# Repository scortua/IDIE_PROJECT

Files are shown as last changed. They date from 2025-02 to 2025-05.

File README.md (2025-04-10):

#### Diseño de un Sistema de Monitoreo de Vibraciones IoT con Conectividad LoRaWAN
# ECI (https://www.escuelaing.edu.co/)PROYECTO INTEGRACIÓN DISPOSITIVOS ELECTRÓNICOS

<p align="center">
  
  
  
  
  
</p>

## Índice
* [PCB](#diseño-pcb)
* [3D](#diseño-3d)

## Entregables del Proyecto

### Entregable 1: Documentación Técnica y Conceptual
La guía se encuentra en el archivo _Markdown_ [Base entregable 1](./ent1.md) y abarca:
- **Introducción:** Presentación del proyecto, la motivación y los objetivos.
- **Detalle del Producto:** Especificaciones técnicas, características físicas y funcionales del dispositivo IoT.
- **Alcance de los Servicios Ofertados:** Descripción de los servicios incluidos, como el diseño de hardware, firmware, pruebas y documentación completa.
- **Exclusiones del Alcance:** Elementos y servicios que no se consideran en el proyecto (producción en masa, logística, etc.).
- **Valor:** Análisis de costos, desglose de inversión y metodologías de cálculo.
- **Cronograma de Trabajo:** Fases del proyecto y tiempo estimado para cada etapa.
- **Tiempo de Entrega:** Fechas clave y plazos para los entregables parciales y finales.

---

### Entregable 2: Diseño y Sustentación Técnica
Disponible en el archivo _Markdown_ [Base entregable 2](./ent2.md), este entregable se compone de:
- **Sustentación del Diseño:** Presentación y defensa del diseño, representando un 30% de la evaluación.
- **Informe Digital Detallado (35%):**
  - Descripción general de la solución y su justificación.
  - Diagramas de bloques que ilustren el flujo y la estructura de la solución.
  - Descripción detallada de cada bloque (funciones y relaciones).
  - Relación entre la solución y los requerimientos solicitados.
  - Especificaciones técnicas de los componentes electrónicos clave (MCU, memorias, fuentes, interfaces, etc.).
  - Diseño esquemático del sistema.
  - Diseño de PCB, presentando cada capa (máscara de componentes, anti-soldadura, crema, cobre y perforaciones).
  - Lista de materiales (BOM List).
  - Modelo 3D del producto final.
  - Cuadro de costos de producción para diferentes volúmenes (1, 10, 100, 500, 1000 y 5000 unidades).
- **Paquete Digital Adicional (35%):**
  - Informe en PDF con toda la documentación.
  - Archivo PDF del esquemático.
  - Archivos GERBER del diseño de la PCB.
  - Archivo BOM en Excel.
  - Archivo STEP o STL del modelo 3D.
  - Hoja de cálculo para el cuadro de costos, con fórmula automática según la cantidad a producir.
  - Hojas de datos (datasheets) de los componentes principales.

---

### Entregable 3: Manuales, Brochure y Prototipo Final
La guía se encuentra en [Base entregable 3](./ent3.md) y comprende:
- **Manual de Usuario:** Documento PDF que explica el funcionamiento y manejo del dispositivo (10%).
- **Brochure del Producto:** Ficha comercial en PDF que resalta las ventajas competitivas y características principales (10%).
- **Informe Digital Actualizado (20%):**
  - Descripción del firmware desarrollado y su funcionamiento.
  - Diagrama de flujo de la aplicación.
  - Detalle de los drivers implementados.
  - Retos y dificultades enfrentadas junto con las soluciones aplicadas.
  - Conclusiones finales y lecciones aprendidas.
  - Inclusión y actualización del paquete digital definido en el Entregable 2.
- **Prototipo Final Funcional:** Durante la presentación, se evaluarán todas las características y funcionalidades estipuladas en el proyecto (60%).

Cada uno de estos entregables está diseñado para garantizar una documentación integral y una validación exhaustiva del proyecto, cubriendo desde la concepción de la idea hasta la demostración práctica del sistema IoT.

# DISEÑO GENERAL
Antes de comenzar es necesario buscar sobre dispositivos similares y si existen, toda la idea de los componentes principales que tienen sus características principales en el diseño y después los requeridos para el funcionamiento de lo necesario.

## Diseño PCB
<p align="center">
  
</p>
<details>
<summary> Dimensiones </summary>
Primer paso fue construir la PCB que entrara a la perfección dentro de la caja seleccionada que se ve a continuación.

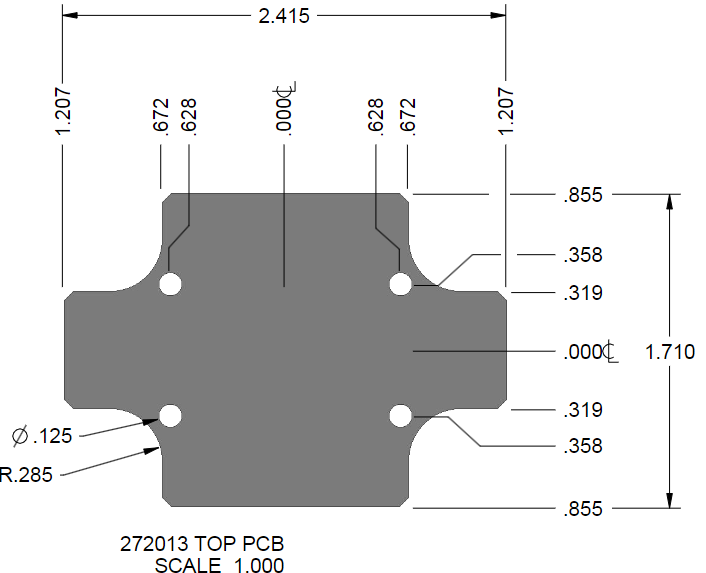
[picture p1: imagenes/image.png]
Caja


Estas medidas se siguieron al pie de la letra para poder diseñar a la perfección la PCB y el circuito que se desea.
</details>

## Componentes
#### Componentes Usados

A continuación se describen los dispositivos fundamentales utilizados en el proyecto, documentados en los archivos PDF disponibles:

- **Socket Batería:** ([1015-socketbattery.pdf](./Documentos/1015-socketbattery.pdf))  
  Se especifica el diseño del conector para integración segura y confiable del paquete de alimentación.

- **Cristal Oscilador:** ([ABS06-cristal.pdf](./Documentos/ABS06-cristal.pdf))  
  Fundamental para la sincronización de circuitos, garantizando estabilidad y precisión en el reloj del sistema.

- **Bobina y Núcleo de Ferrita:** ([core_ferrita-coil.pdf](./Documentos/core_ferrita-coil.pdf))  
  Componentes críticos en la filtración y manejo de interferencias electromagnéticas en el circuito.

- **Convertidor Serial:** ([DS_FT234XD-serialconverter.pdf](./Documentos/DS_FT234XD-serialconverter.pdf))  
  Facilita la comunicación entre el microcontrolador y dispositivos externos mediante interfaces USB y serie.

- **Unidad de Medición Inercial (IMU):** ([FXLS8974CFR3-imu.pdf](./Documentos/FXLS8974CFR3-imu.pdf))  
  Incorpora sensores que permiten la detección y el análisis de movimientos y vibraciones, contribuyendo a la monitorización del estado del dispositivo.

- **Sensor de Efecto Hall:** ([hall_efect-sensor.pdf](./Documentos/hall_efect-sensor.pdf))  
  Utilizado para detectar cambios en campos magnéticos, lo que aporta datos relevantes en aplicaciones de control de propiedad magnética.

- **LED RGB:** ([HB_CLY6D-rgb_led.pdf](./Documentos/HB_CLY6D-rgb_led.pdf))  
  Proporciona indicadores visuales para el estado del sistema, útil para diagnósticos o notificaciones.

- **Módulo LoRa:** ([LoRa_E5_module.pdf](./Documentos/LoRa_E5_module.pdf))  
  Es el componente clave para la conexión IoT a través de la red LoRaWAN, permitiendo la transmisión de datos a larga distancia.

- **Transistor y MOSFET:** ([transistor.pdf](./Documentos/transistor.pdf), [SI2305B_SOT_23-mosfet.pdf](./Documentos/SI2305B_SOT_23-mosfet.pdf))  
  Empleados para la gestión de señales y el control de potencia dentro del circuito integrado.

- **Microcontrolador:** ([stm32l071v8-micro.pdf](./Documentos/stm32l071v8-micro.pdf))  
  El cerebro del sistema, encargado de coordinar las comunicaciones, procesar las señales de los sensores y gestionar las acciones del dispositivo.

- **Protección de Diodos:** ([usblc6_2SY6-diode-protection.pdf](./Documentos/usblc6_2SY6-diode-protection.pdf))  
  Asegura la integridad del circuito frente a sobretensiones y otros picos de corriente, protegiendo los componentes sensibles.

- **Antena:** ([W2311-antenna.pdf](./Documentos/W2311-antenna.pdf))
  La antena es un componente crítico en la conexión IoT a través de LoRaWAN. Su función es asegurar una comunicación fiable y de largo alcance al transmitir y recibir datos en frecuencias específicas.
  - **Tipo:** Diseñada para ser compacta y eficiente, comúnmente usando tecnología PCB o de hilo.
  - **Frecuencia Operativa:** Se adapta a bandas como 433 MHz, 868 MHz o 915 MHz, según las normativas locales.
  - **Ganancia y Eficiencia:** Optimizada para maximizar el alcance y garantizar una recepción estable.

## Esquemático
### Desarrollo del Esquemático

Para el desarrollo del esquemático se utilizó el software Eagle, lo que permitió integrar de forma precisa todos los elementos del circuito. Los componentes se seleccionaron desde Mouser y se incorporaron mediante el gestor de librerías Library Loader, asegurando una integración coherente y validada antes de avanzar al diseño de PCB.
Para la hoja 1 se tiene:
<p align="center">
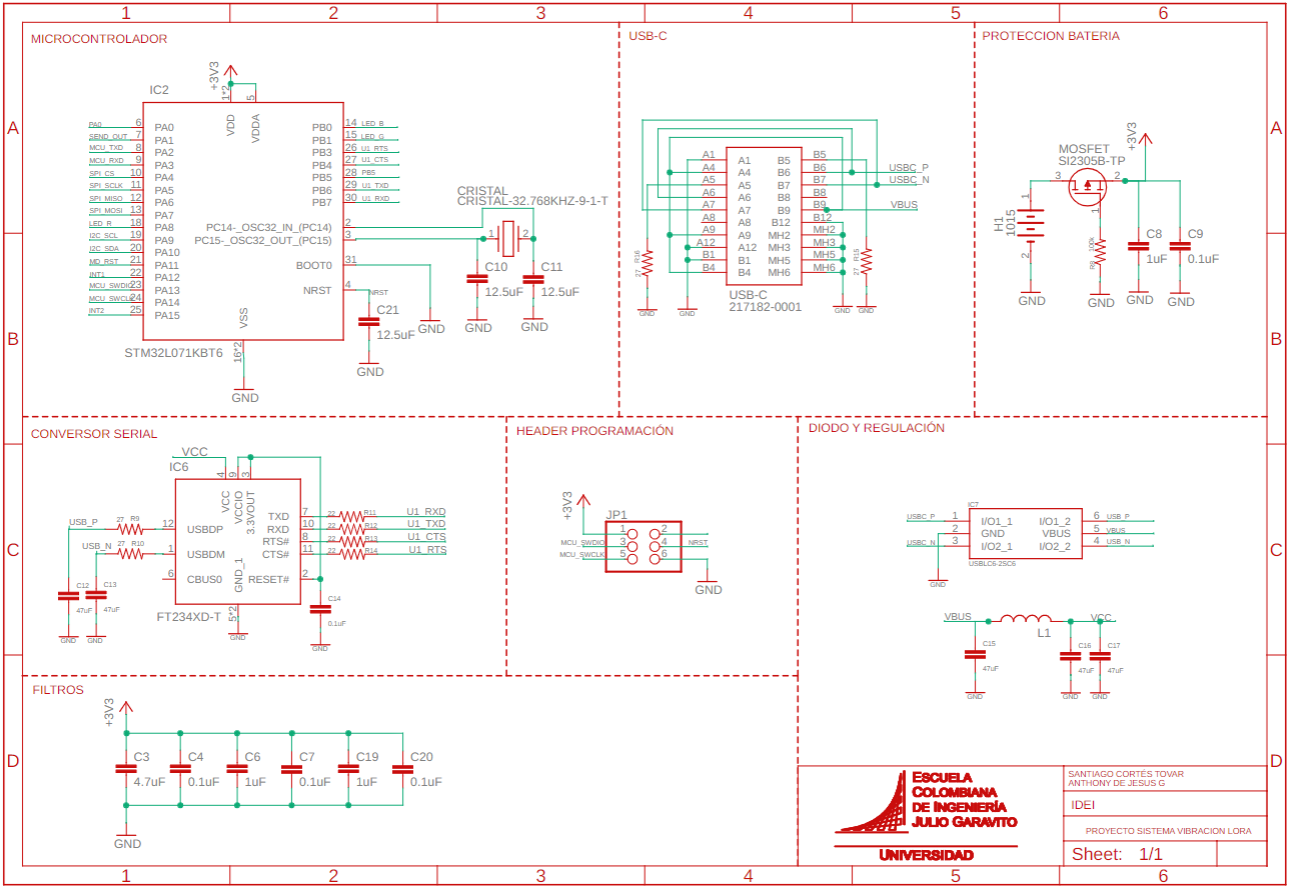
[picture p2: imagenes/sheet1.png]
Esquemático1
  
</p>
Y para la hoja 2 se tiene:
<p align="center">
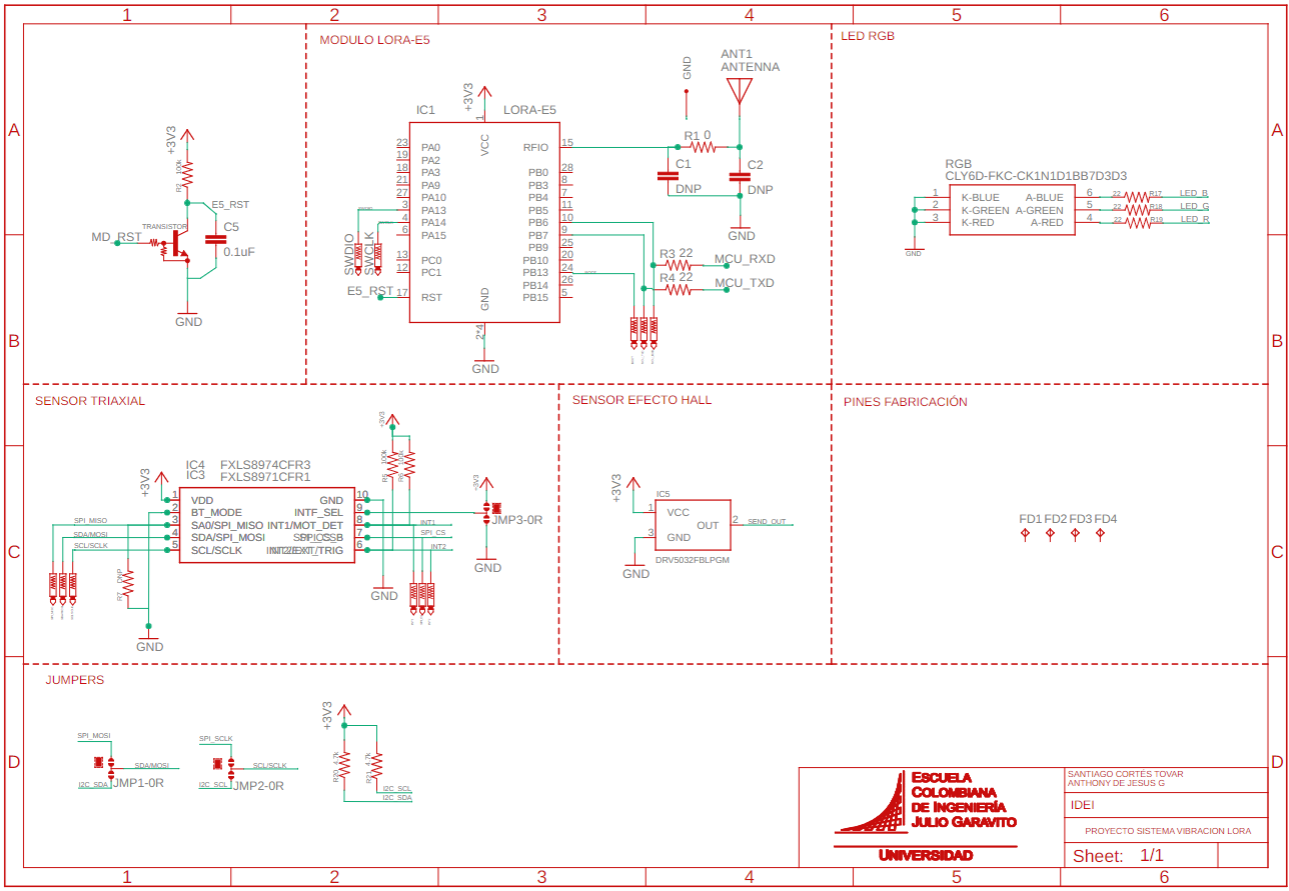
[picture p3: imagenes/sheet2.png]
Esquemático2
  
</p>

## PCB
Ahora, con el diseño del esquemático como se planteo es construirlo en un modelo de caja

<p align="center">
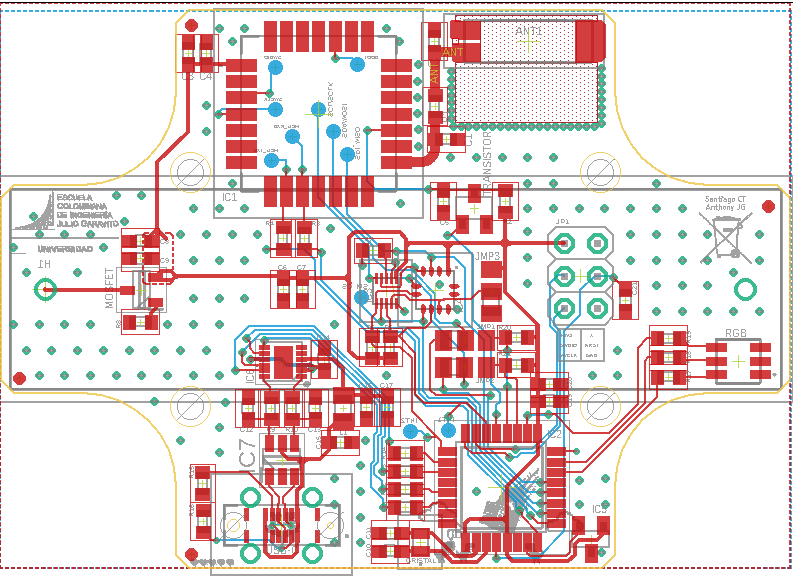
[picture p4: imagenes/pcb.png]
PCB
  
</p>

## Diseño 3D
<p align="center">
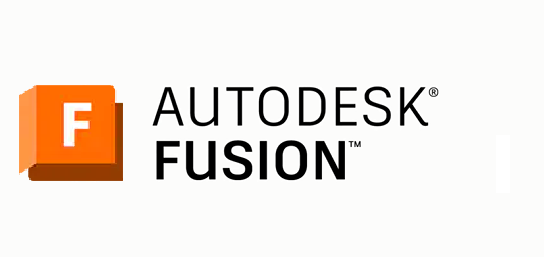
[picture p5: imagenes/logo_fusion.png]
  
</p>

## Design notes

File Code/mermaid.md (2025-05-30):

```mermaid
---
config:
  look: neo
  layout: elk
---
flowchart TD
    BATERIA["Bateria"]
    PROTECCION["Protección Electrónica"]
    USB["Concexión USB-C"]
    SERIAL["Modulo<br>Serial"]
    ENERGIA["Alimentación Principal<br>del Sistema"]
    MICRO["Microcontrolador"]
    LORA["Modulo LoRa"]
    ANTENA["Antena"]
    MQTT["Envio datos<br>por Protocolo"]
    IMAN["Sensor<br>Detector Imanes"]
    IMU["Sensor Triaxial<br>Medición Vibración"]
    RGB["Luz RGB<br>Indica Funcionamiento"]

    subgraph ALIMENTACION
        USB --> PROTECCION
        BATERIA --> PROTECCION
    end
    subgraph INALAMBRICO
        LORA --> ANTENA
    end
        
    BATERIA --> ENERGIA
    PROTECCION -- Datos/Energia --> SERIAL
    SERIAL -- Programación --> MICRO
    IMU <-- Comunicación<br>Constante --> MICRO
    IMAN -- Activar<br>Desactivar --> MICRO
    MICRO <-- Comucicación<br>Parcial --> INALAMBRICO
    MICRO -- Indicador --> RGB
    INALAMBRICO --> MQTT
```
next
```mermaid
%% ESP32-S3 Weather Station with 1.69" Display - Block Diagram
graph TD
    %% ========== Input Section ==========
    INTERNET[["Internet<br>(WiFi)"]] --> ESP32
    NTP[["NTP Server<br>(time.nist.gov)"]] --> ESP32
    API[["Weather API<br>(api.weatherapi.com)"]] --> ESP32

    %% ========== Main Controller ==========
    subgraph ESP32-S3 ["ESP32-S3 Controller NanoFF"]
        FIRMWARE[["Firmware"]]
        WEB_SERVER[["Web Server<br>Port 80"]]
        NTP_CLIENT[["NTP Client"]]
        API_CLIENT[["API Client"]]
        DISPLAY_DRV[["Display Driver"]]
    end

    %% ========== Output Section ==========
    ESP32 --> DISPLAY[["1.69' Display<br>240×280 SPI<br>• Date/Time<br>• Temperature<br>• Humidity"]]
    ESP32 --> WEB_UI[["Local Web UI<br>• Real-time Data<br>• History Graphs<br>• Configuration"]]

    %% ========== Data Flow ==========
    FIRMWARE -->|Control| NTP_CLIENT
    FIRMWARE -->|Control| API_CLIENT
    FIRMWARE -->|Control| DISPLAY_DRV
    FIRMWARE -->|Control| WEB_SERVER
    
    NTP_CLIENT -->|Sync Time| FIRMWARE
    API_CLIENT -->|JSON Data| FIRMWARE
    DISPLAY_DRV -->|SPI Comm| DISPLAY
    WEB_SERVER -->|HTTP Response| WEB_UI

    %% ========== Styling ==========
    classDef hardware fill:#4CAF50,stroke:#388E3C,color:white
    classDef software fill:#2196F3,stroke:#1565C0,color:white
    classDef service fill:#FF9800,stroke:#F57C00,color:black
    classDef output fill:#9C27B0,stroke:#7B1FA2,color:white

    class INTERNET,NTP,API service
    class ESP32-S3 hardware
    class FIRMWARE,NTP_CLIENT,API_CLIENT,DISPLAY_DRV,WEB_SERVER software
    class DISPLAY,WEB_UI output
```
next
```mermaid
%% Diagrama de Conexiones ESP32-S3 Touch LCD 1.69"
graph TB
    %% ===== Núcleo Principal =====
    ESP32["ESP32-S3\n(NanoFramework)\n---\nWiFi/BT\nDual Core\n240MHz"] -->|SPI| LCD
    ESP32 -->|I2C| TOUCH
    ESP32 -->|I2C| RTC
    ESP32 -->|PWM| BUZZER
    ESP32 -->|RF| ANTENA

    %% ===== Periféricos =====
    LCD["Pantalla 1.69\nST7789V\n---\n240x280px\nSPI 4-wire"]
    
    TOUCH["Controlador Táctil\nFT6236\n---\nResolución: 1024x1024\nI2C@400kHz"]
    
    RTC["Reloj de Tiempo Real\nDS3231\n---\n±2ppm\nBatería CR2032"]
    
    BUZZER["Buzzer Pasivo\n---\nFrecuencia: 2-4kHz\nPWM 8-bit"]
    
    ANTENA["Antena PCB\n---\n2.4GHz\nGanancia: 2dBi"]

    %% ===== Estilos =====
    classDef mcu fill:#4CAF50,stroke:#2E7D32,color:white
    classDef display fill:#2196F3,stroke:#0D47A1,color:white
    classDef sensor fill:#FF9800,stroke:#E65100,color:black
    classDef comm fill:#9C27B0,stroke:#6A1B9A,color:white

    class ESP32 mcu
    class LCD,TOUCH display
    class RTC,BUZZER sensor
    class ANTENA comm
    ```

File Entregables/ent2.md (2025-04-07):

# Entregable 2

Este documento presenta el segundo entregable del proyecto IDIE, estructurado en secciones claras que detallan los avances y la documentación relevante. A continuación se describen las secciones y el contenido que debe incluirse en cada una:

## Objetivos y Alcance
Aquí se describen los objetivos alcanzados y se define el alcance de la solución propuesta. Se incluye:
- Descripción de los logros hasta la fecha.
- Definición del marco y límites de la solución propuesta.
- Aspectos técnicos claves y metas a corto y largo plazo.

## Documentación Técnica
Esta sección recopila toda la información técnica relacionada con el proyecto. Los contenidos pueden incluir:
- Análisis de requerimientos.
- Diagramas (por ejemplo, de flujo, arquitectónicos, de componentes electrónicos).
- Especificaciones de componentes y protocolos para la implementación tanto electrónica como de software.
- Metodologías y lineamientos técnicos.

## Estructura del Contenido
Se organiza el entregable en secciones para facilitar su lectura y comprensión. Se recomienda:
- Un índice o tabla de contenido inicial.
- Divisiones claras entre información técnica, analítica y de validación.
- Uso de títulos y subtítulos para delimitar cada área de contenido.

## Revisión y Validación
Esta parte se centra en el control de calidad del entregable y en la recepción de retroalimentación. Se debe incluir:
- Resultados y comentarios de revisiones por parte de tutores y equipo.
- Identificación de áreas de mejora.
- Registro de validaciones y aprobación final del documento.

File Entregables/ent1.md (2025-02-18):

# Diseño de un Sistema de Monitoreo de Vibraciones IoT con Conectividad LoRaWAN

**Autores:**  
[Nombres de los autores]

**Profesor:**  
Ing. [Nombre del profesor]

**Escuela Colombiana de Ingeniería Julio Garavito**  
Integración de Dispositivos Electrónicos  
Bogotá D.C.  
Febrero 2025

## Tabla de Contenido
1. Introducción
2. Detalle del Producto
3. Alcance de los Servicios Ofertados
4. Servicios No Ofertados
5. Valor
6. Cronograma de Trabajo
7. Tiempo de Entrega

## 1. Introducción
- **Equipo**: Descripción del equipo y su experiencia.
- **Objetivo**: Objetivo del proyecto y justificación.

Somos un equipo de estudiantes de Ingeniería Electrónica comprometidos con el desarrollo de soluciones tecnológicas innovadoras para la industria. Nuestro enfoque se centra en la integración de tecnologías IoT para el monitoreo y mantenimiento predictivo de maquinaria industrial.

El mantenimiento predictivo basado en el análisis de vibraciones es una técnica fundamental en la industria moderna, permitiendo detectar fallos potenciales antes de que ocurran fallas críticas. Según estudios recientes, la implementación de sistemas de monitoreo de vibraciones puede reducir los costos de mantenimiento hasta en un 25% y aumentar la vida útil de la maquinaria en un 30%.

Nuestro proyecto propone el desarrollo de un dispositivo IoT de monitoreo de vibraciones que integra tecnología LoRaWAN, permitiendo una supervisión continua y en tiempo real del estado de la maquinaria industrial, con un enfoque en la eficiencia energética y la conectividad de largo alcance.

## 2. Detalle del Producto
- **Descripción**: Funcionalidades y características técnicas del dispositivo.
- **Especificaciones**: Dimensiones, materiales, autonomía, etc.

El producto es un sistema compacto de monitoreo de vibraciones con las siguientes características principales:

### Características Físicas
- Dimensiones: 100x100x60 mm máximo
- Carcasa: Fabricada en plástico ABS/PLA de grado industrial
- Diseño robusto para ambientes industriales
- Montaje flexible mediante sistema de sujeción industrial

### Características Técnicas
- Sensor de vibración de 3 ejes (X-Y-Z)
- Rango de medición: ±16g
- Frecuencia de muestreo: 1600 Hz
- Conectividad LoRaWAN Clase A (Banda AU915)
- Batería de larga duración (>1 año)
- Procesador de bajo consumo
- Memoria para almacenamiento local de datos

### Funcionalidades
- Medición continua de vibraciones en tres ejes
- Cálculo de métricas clave:
  - Vibración máxima por eje
  - Promedio de vibración
  - Desviación estándar
- Monitoreo de temperatura del dispositivo
- Indicador de nivel de batería
- Transmisión periódica de datos cada 15 minutos
- Interfaz de configuración para parámetros de operación

## 3. Alcance de los Servicios Ofertados
- **Lista de servicios**: Diseño de hardware, firmware, conectividad, pruebas, documentación, entrega de prototipo.
- **Garantías**: Detalles de la garantía y soporte técnico.
### Diseño y Desarrollo
- Diseño completo del hardware del dispositivo
- Desarrollo del firmware embebido
- Diseño de PCB y selección de componentes
- Desarrollo de protocolos de comunicación LoRaWAN
- Integración con plataformas MQTT
- Diseño de carcasa protectora

### Documentación
- Esquemáticos completos del diseño
- Archivos de fabricación de PCB
- Documentación técnica detallada
- Manual de usuario
- Guías de instalación y configuración

### Pruebas y Validación
- Pruebas de funcionamiento en laboratorio
- Validación de durabilidad de batería
- Pruebas de comunicación LoRaWAN
- Calibración de sensores
- Verificación de precisión de mediciones

### Entregables Físicos
- Prototipo funcional completo
- PCB ensamblada y probada
- Carcasa protectora
- Accesorios de montaje

### Garantías
- Tiempo de prueba
- Problemas en caja
- Problemas del dispositivo

## 4. Servicios No Ofertados
- **Lista de servicios no incluidos**: Producción en masa, logística, desarrollo de aplicaciones, soporte extendido.
- **Explicación**: Razones por las que no están incluidos.
- Instalación en sitio del dispositivo
- Mantenimiento continuo post-entrega
- Desarrollo de aplicaciones móviles personalizadas
- Servicios de almacenamiento en la nube
- Capacitación presencial para usuarios finales
- Certificaciones internacionales
- Soporte técnico extendido
- Actualizaciones de firmware posteriores a la entrega

## 5. Valor
- **Costos**: Mano de obra, materiales, gastos operativos, impuestos.
- **Forma de pago**: Pago inicial y pagos periódicos.
El costo de producción objetivo para 1000 unidades es de $80 USD por unidad, incluyendo:
- Componentes electrónicos
- PCB fabricación y ensamblaje
- Carcasa y materiales
- Costos de importación
- Gastos administrativos
- Margen de producción

Calculo fijo mensual (alquiler, servicios, comida...)
Gastos anuales divididos por 12, dividir al tiempo de trabajo con gastos y ahora se agregan las ganancias.

## 6. Cronograma de Trabajo
- **Actividades**: Lista de actividades y fechas estimadas.
- **Diagrama**: Cronograma visual (opcional).
### Fase 1: Diseño Inicial (Semanas 1-3)
- Selección de componentes
- Diseño esquemático
- Simulaciones iniciales

### Fase 2: Desarrollo de Hardware (Semanas 4-6)
- Diseño de PCB
- Diseño de carcasa
- Prototipo inicial

### Fase 3: Desarrollo de Firmware (Semanas 7-9)
- Programación del microcontrolador
- Implementación LoRaWAN
- Integración MQTT

### Fase 4: Integración y Pruebas (Semanas 10-12)
- Ensamblaje de prototipo
- Pruebas de funcionamiento
- Optimización de consumo

### Fase 5: Documentación y Finalización (Semanas 13-16)
- Elaboración de documentación
- Pruebas finales
- Preparación de entregables

## 7. Tiempo de Entrega
- **Plazo**: 16 semanas.
- **Justificación**: Explicación del tiempo necesario.
El proyecto se desarrollará en un período de 16 semanas, con entregables parciales según el siguiente calendario:

- Primer Entregable: 22 de febrero de 2025
- Segundo Entregable: 29 de marzo de 2025
- Entrega Final: 17 de mayo de 2025

Los tiempos establecidos incluyen márgenes para ajustes y correcciones, asegurando la calidad del producto final y el cumplimiento de todos los requerimientos especificados.

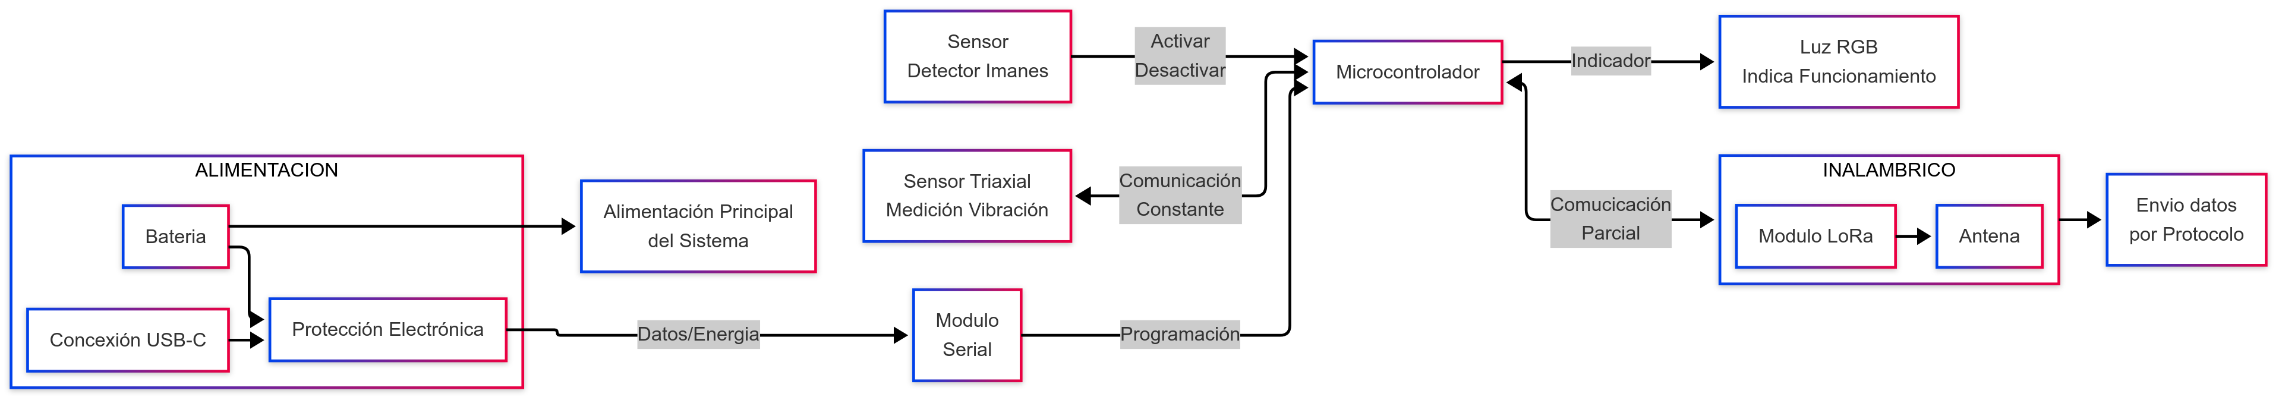
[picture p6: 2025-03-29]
imagenes/Bloques Funcionamiento.png

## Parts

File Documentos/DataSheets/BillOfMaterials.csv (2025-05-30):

Qty | Value | Device | Package | Parts | Description | ARROW_PART_NUMBER | ARROW_PRICE-STOCK | DESCRIPTION | HEIGHT | MANUFACTURER_NAME | MANUFACTURER_PART_NUMBER | MOUSER_PART_NUMBER | MOUSER_PRICE-STOCK | POPULARITY | SPICEPREFIX | TP_SIGNAL_NAME
1 |  | L-US | C0805K | L1 | INDUCTOR, American symbol
1 |  | MUN2211T1-NPN_DRIVER-SC59-BEC | SC59-BEC | TRANSISTOR | NPN Bias Resistor Transistor |  |  |  |  |  |  |  |  | 0 | J
1 |  | PINHD-2X3 | 2X03 | JP1 | PIN HEADER |  |  |  |  |  |  |  |  | 62
1 | 0 | R-US_R0603 | R0603 | R1 | RESISTOR, American symbol |  |  |  |  |  |  |  |  | 77 | R
6 | 0.1uF | C-EUC0603 | C0603 | C4, C5, C7, C9, C14, C20 | CAPACITOR, European symbol |  |  |  |  |  |  |  |  | 73 | C
3 | 0R-JUMPA | 0R-JUMPA | A0R-JMP | JMP1, JMP2, JMP3 | SMD 0R 0805 Jumper |  |  |  |  |  |  |  |  | 3
4 | 100k | R-US_R0603 | R0603 | R2, R5, R6, R8 | RESISTOR, American symbol |  |  |  |  |  |  |  |  | 77 | R
1 | 1015 | 1015 | 1015 | H1 | Cylindrical Battery Contacts, Clips, Holders & Springs AA PC Battery HOLDER |  |  | Cylindrical Battery Contacts, Clips, Holders & Springs AA PC Battery HOLDER | mm | Keystone Electronics | 1015 | 534-1015 | https://www.mouser.co.uk/ProductDetail/Keystone-Electronics/1015?qs=73q%2FgRcW4F2OhJTPPQWZpA%3D%3D
3 | 12.5uF | C-EUC0603 | C0603 | C10, C11, C21 | CAPACITOR, European symbol |  |  |  |  |  |  |  |  | 73 | C
3 | 1uF | C-EUC0603 | C0603 | C6, C8, C19 | CAPACITOR, European symbol |  |  |  |  |  |  |  |  | 73 | C
1 | 217182-0001 | 217182-0001 | 2171820001 | USB-C | USB-C,VERT SMT,16P 6.40mm HT |  |  | USB-C,VERT SMT,16P 6.40mm HT | 7.6mm | Molex | 217182-0001 | 538-217182-0001 | https://www.mouser.co.uk/ProductDetail/Molex/217182-0001?qs=DRkmTr78QATos3F5kgk4kw%3D%3D
9 | 22 | R-US_R0603 | R0603 | R3, R4, R11, R12, R13, R14, R17, R18, R19 | RESISTOR, American symbol |  |  |  |  |  |  |  |  | 77 | R
4 | 27 | R-US_R0603 | R0603 | R9, R10, R15, R16 | RESISTOR, American symbol |  |  |  |  |  |  |  |  | 77 | R
2 | 4.7k | R-US_R0603 | R0603 | R20, R21 | RESISTOR, American symbol |  |  |  |  |  |  |  |  | 77 | R
1 | 4.7uF | C-EUC0603 | C0603 | C3 | CAPACITOR, European symbol |  |  |  |  |  |  |  |  | 73 | C
5 | 47uF | C-EUC0603 | C0603 | C12, C13, C15, C16, C17 | CAPACITOR, European symbol |  |  |  |  |  |  |  |  | 73 | C
1 | ANTENNA | ANTENNA | ANTENNA | ANT1 | PULSE LARSEN ANTENNAS - W3211 - CERAMIC ON GROUND ANTENNA, 902-928MHZ |  |  | PULSE LARSEN ANTENNAS - W3211 - CERAMIC ON GROUND ANTENNA, 902-928MHZ | 5mm | Pulse Electronics | W3211 | 673-W3211 | https://www.mouser.co.uk/ProductDetail/PulseLarsen-Antennas/W3211?qs=l7cgNqFNU1g5WBF3n%252BWoMg%3D%3D
1 | CLY6D-FKC-CK1N1D1BB7D3D3 | CLY6D-FKC-CK1N1D1BB7D3D3 | PLCC6 | RGB | LED Blue/Green/Red 6-Pin PLCC T/R Cree CLY6D-FKC-CK1N1D1BB7D3D3, CLY6D-FKC Series RGB LED, 480 (Blue) nm, 540 (Green) nm, 624 (Red) nm PLCC 6 |  |  | LED Blue/Green/Red 6-Pin PLCC T/R Cree CLY6D-FKC-CK1N1D1BB7D3D3, CLY6D-FKC Series RGB LED, 480 (Blue) nm, 540 (Green) nm, 624 (Red) nm PLCC 6 | mm | CREE LED | CLY6D-FKC-CK1N1D1BB7D3D3 | 941-CLY6DFKCCK1N1D1B | https://www.mouser.co.uk/ProductDetail/Cree-LED/CLY6D-FKC-CK1N1D1BB7D3D3?qs=3ZbGupGMFUcwV8ee%2FC0TnQ%3D%3D
1 | CRISTAL-32.768KHZ-9-1-T | CRISTAL-32.768KHZ-9-1-T | CRISTAL-32.768 | CRISTAL | ABRACON - ABS06-32.768KHZ-9-1-T - CRYSTAL, 32.768KHZ, 9PF, 2 X 1.2MM |  |  | ABRACON - ABS06-32.768KHZ-9-1-T - CRYSTAL, 32.768KHZ, 9PF, 2 X 1.2MM | 0.6mm | ABRACON | ABS06-32.768KHZ-9-1-T | 815-ABS06-32.7K-9-T | https://www.mouser.co.uk/ProductDetail/ABRACON/ABS06-32.768KHZ-9-1-T?qs=3LVMET7lfiNjL9rrGxo%252ByA%3D%3D
2 | DNP | C-EUC0603 | C0603 | C1, C2 | CAPACITOR, European symbol |  |  |  |  |  |  |  |  | 73 | C
1 | DNP | R-US_R0603 | R0603 | R7 | RESISTOR, American symbol |  |  |  |  |  |  |  |  | 77 | R
1 | DRV5032FBLPGM | DRV5032FBLPGM | SOT23 | IC5
1 | FT234XD-T | FT234XD-T | SON45P300X300X80-13N | IC6 | USB Interface IC USB to Basic Serial UART IC |  |  | USB Interface IC USB to Basic Serial UART IC | 0.8mm | FTDI(Future Designs) | FT234XD-T
1 | FXLS8971CFR1 | FXLS8971CFR1 | FXLS8971CFR1 | IC4 | 3-Axis Low-g Accelerometer FXLS8971CF is available in a 3 mm x 3 mm x 1.25 mm 12-pin QFN package with 0.65 mm pitch and wettable flanks |  |  | 3-Axis Low-g Accelerometer FXLS8971CF is available in a 3 mm x 3 mm x 1.25 mm 12-pin QFN package with 0.65 mm pitch and wettable flanks | 1.3mm | NXP | FXLS8971CF
1 | FXLS8974CFR3 | FXLS8974CFR3 | FXLS8974CFR3 | IC3 | Accelerometer X, Y, Z Axis +/-2g, 4g, 8g, 16g 1.6kHz 10-DFN (2x2) |  |  | Accelerometer X, Y, Z Axis +/-2g, 4g, 8g, 16g 1.6kHz 10-DFN (2x2) | 1mm | NXP | FXLS8974CFR3 | 771-FXLS8974CFR3 | https://www.mouser.co.uk/ProductDetail/NXP-Semiconductors/FXLS8974CFR3?qs=QNEnbhJQKva4g7R74%252BwIOg%3D%3D
1 | LORA-E5 | LORA-E5 | LORA-E5 | IC1 | Sub-GHz Modules LoRa-E5 Wireless Module LoRa-E5 has a 28-pin SMD package |  |  | Sub-GHz Modules LoRa-E5 Wireless Module LoRa-E5 has a 28-pin SMD package | 2.5mm | Seeed Studio | 317990687 | 713-317990687 | https://www.mouser.co.uk/ProductDetail/Seeed-Studio/317990687?qs=hd1VzrDQEGhZOj13wvzSLA%3D%3D
11 | PTR1TP11R | PTR1TP11R | TP11R | BOOT, INT1, INT2, MCU_RXD, MCU_TXD, SCL/SCLK, SDA/MOSI, SPI_CS, SPI_MISO, SWCLK, SWDIO | TEST PIN |  |  |  |  |  |  |  |  | 1
1 | SI2305B-TP | SI2305B-TP | SOT95P237X125-3N | MOSFET | P-Channel 20 V 4.2A (Tj) 1.4W Surface Mount SOT-23 |  |  | P-Channel 20 V 4.2A (Tj) 1.4W Surface Mount SOT-23 | 1.25mm | MCC | SI2305B-TP | 833-SI2305B-TP | https://www.mouser.co.uk/ProductDetail/Micro-Commercial-Components-MCC/SI2305B-TP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
1 | STM32L071KBT6 | STM32L071KBT6 | STM32L071KBT6 | IC2 | MCU 32-bit STM32 ARM Cortex M0+ RISC 128KB Flash 2.5V/3.3V 32-Pin LQFP Tray |  |  | MCU 32-bit STM32 ARM Cortex M0+ RISC 128KB Flash 2.5V/3.3V 32-Pin LQFP Tray | 1.6mm | STMicroelectronics | STM32L071KBT6 | 511-STM32L071KBT6 | https://www.mouser.co.uk/ProductDetail/STMicroelectronics/STM32L071KBT6?qs=mKNKSX85ZJf5FR8Umx1PEQ%3D%3D
4 | TPTP10R | TPTP10R | TP10R | FD1, FD2, FD3, FD4 | Test pad |  |  |  |  |  |  |  |  | 3
1 | USBLC6-2SC6 | USBLC6-2SC6 | SOT95P280X145-6N | IC7 | TVS Diode Array Uni-Directional USBLC6-2SC6 17V, SOT-23 6-Pin |  |  | TVS Diode Array Uni-Directional USBLC6-2SC6 17V, SOT-23 6-Pin | 1.45mm | STMicroelectronics | USBLC6-2SC6 | 511-USBLC6-2SC6 | https://www.mouser.co.uk/ProductDetail/STMicroelectronics/USBLC6-2SC6?qs=po45yt2pPpu%2FhNIlwQdTlg%3D%3D

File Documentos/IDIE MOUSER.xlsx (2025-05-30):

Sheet: COMPONENTES
 |  |  |  |  | 1 | 10 | 100 | 500 | 1000
Mouser N,º | Fabricante N,º | Fabricante | Descripción | Cantidad | Ext,: (USD)
667-TL4903S | TL4903S | Tadiran Batteries | Batería electrónica AA 2,4Ah | 1 | $8.39 | $83.90 | $567.00 | $2680.00 | $4970.00
713-317990687 | 317990687 | Seeed Studio | Módulos Sub-GHz Wio-E5 Wireless Module (Bulk)-28P | 1 | $8.73 | $87.30 | $873.00 | $4365.00 | $8730.00
511-STM32L071KBT6 | STM32L071KBT6 | STMicroelectronics | Microcontroladores ARM - MCU Ultra-low-power Arm Cortex-M0+ MCU 128-Kbytes of Flash , 32 MHz CPU | 1 | $3.70 | $28.20 | $244.00 | $1110.00 | $2080.00
534-1015 | 1015 | Keystone Electronics | Contactos, clips, soportes y resortes para batería cilíndrica AA PC Battery HOLDER | 1 | $2.42 | $24.20 | $209.00 | $915.00 | $1660.00
771-FXLS8974CFR3 | FXLS8974CFR3 | NXP | Acelerómetros 3-axis MEMS accelerometer for industrial and medical IoT applications requiring ultra-low power wake up on motion | 1 | $3.02 | $24.20 | $208.00 | $875.00 | $1680.00
673-W3211 | W3211 | Pulse | Antenas Ant Cer 902-928MHz 10x3,2x5mm | 1 | $1.99 | $14.80 | $131.00 | $555.00 | $1050.00
621-DDTC143XCA-7-F | DDTC143XCA-7-F | Diodes Incorporated | Transistores digitales 200MW 4,7K 10K | 1 | $0.20 | $1.08 | $4.80 | $24.00 | $41.00
833-SI2305B-TP | SI2305B-TP | Micro Commercial Components (MCC) | Transistor metal-óxido-semiconductor de efecto de campo (MOSFET) -20V, -4,2A,PChannel Mosfet | 1 | $0.31 | $2.11 | $1.90 | $54.50 | $97.00 | extra
815-ABS06-32,7K-9-T | ABS06-32,768KHZ-9-1-T | ABRACON | Cristales 32,768 KHZ +/-10PPM 9,0PF | 1 | $1.13 | $8.66 | $75.70 | $282.50 | $553.00
595-DRV5032FBLPGM | DRV5032FBLPGM | Texas Instruments | Sensores magnéticos / de efecto Hall montados en placa Low power (5 Hz <1u A) low voltage (up | 1 | $0.34 | $2.61 | $20.40 | $86.00 | $161.00
895-FT234XD-T | FT234XD-T | FTDI | Interfaz IC USB USB to Basic Serial UART IC | 1 | $2.26 | $22.60 | $212.00 | $880.00 | $1720.00
941-CLY6DFKCCK1N1D1B | CLY6D-FKC-CK1N1D1BB7D3D3 | Cree LED | Luces LED multicolor RGB SMD | 1 | $0.43 | $3.92 | $38.40 | $188.50 | $348.00
875-MI0805K110R-10 | MI0805K110R-10 | Laird Performance Materials | Núcleos de ferrita 11ohms 100MHz 1,5A Monolithic 0805 SMD | 1 | $0.21 | $0.96 | $8.70 | $33.50 | $58.00
640-USB4145-3-0170-C | USB4145-03-0170-C | GCT | Conectores USB USB-C Rec 3u" Vert 16P SMT 1,7mm TH stakes H7,46mm T+R+Cap | 1 | $1.02 | $8.31 | $67.80 | $312.50 | $578.00
511-USBLC6-2SC6 | USBLC6-2SC6 | STMicroelectronics | Diodos de protección contra ESD / Diodos TVS ESD Protection Low Cap | 1 | $0.36 | $2.43 | $16.30 | $63.50 | $114.00
603-AF0603JR-070RL | AF0603JR-070RL | YAGEO | Resistores de película gruesa - SMD 0 Ohms 100 mW 0603 5 % AEC-Q200 | 7 | $0.70 | $0.70 | $5.60 | $24.50 | $14.00
80-C0603C104M4RACTM | C0603C104M4RACTM | KEMET | Capacitores cerámicos de capas múltiples (MLCC) - SMD/SMT 16volts 0,1uF X7R 20% | 6 | $0.60 | $3.30 | $14.40 | $63.00 | $102.00
667-ERA-3AED104V | ERA-3AED104V | Panasonic | Resistores de película fina - SMD 0603 100Kohms 25ppm 0,5% AEC-Q200 | 4 | $0.40 | $2.08 | $18.00 | $80.00 | $160.00
963-MLASL168BB5106MT | MLASL168BB5106MTNB33 | TAIYO YUDEN | Capacitores cerámicos de capas múltiples (MLCC) - SMD/SMT 10V 10uF X5R 0603 20% | 3 | $0.48 | $3.00 | $16.80 | $54.00 | $108.00
187-CL10A105KP8NNNC | CL10A105KP8NNNC | Samsung Electro-Mechanics | Capacitores cerámicos de capas múltiples (MLCC) - SMD/SMT 1uF+/-10% 10V X5R 16 0603 | 3 | $0.30 | $0.75 | $4.80 | $2.40 | $33.00
667-ERA-3AHD220V | ERA-3AHD220V | Panasonic | Resistores de película fina - SMD 0603 22ohms 50ppm 0,5% AEC-Q200 | 9 | $1.53 | $7.20 | $48.60 | $216.00 | $333.00
667-ERA-3AHD270V | ERA-3AHD270V | Panasonic | Resistores de película fina - SMD 0603 27ohms 50ppm 0,5% AEC-Q200 | 4 | $0.68 | $3.20 | $24.40 | $92.00 | $184.00
667-ERA-3AEB472V | ERA-3AEB472V | Panasonic | Resistores de película fina - SMD 0603 1/10W 4,7Kohms | 2 | $0.20 | $1.16 | $11.00 | $45.00 | $90.00
187-CL10A475KP8NNNL | CL10A475KP8NNNL | Samsung Electro-Mechanics | Capacitores cerámicos de capas múltiples (MLCC) - SMD/SMT 4,7uF+/-10% 10V X5R 0603 | 1 | $0.10 | $0.35 | $2.00 | $7.00 | $12.00
187-CL10A476MQ8QRNC | CL10A476MQ8QRNC | Samsung Electro-Mechanics | Capacitores cerámicos de capas múltiples (MLCC) - SMD/SMT 47uF+/-20% 6,3V X5R 0603 | 5 | $6.00 | $28.10 | $207.00 | $935.00 | $1750.00
NA | NA
NA | NA
 |  |  |  |  | $45.50 | $365.12 | $3030.60 | $13943.90 | $26626.00
 |  | NA | Envio Placas | 1 | $10.17 | $11.02 | $28.82 | $111.95 | $167.76
 |  | NA | Envio componentes | 1 | $60.00 | $60.00 | $60.00 | $60.00 | $60.00
 |  |  |  |  | $70.17 | $71.02 | $88.82 | $171.95 | $227.76
NA | NA | NA | Placa PCB | 1 | $4.00 | $5.00 | $20.50 | $67.70 | $126.70

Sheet: PRODUCCION
Unidades | Costo de componentes | Costo de producción | Costo de envío y nacionalización | Costo total | Costo por unidad
1 | $45.50 | $81.50 | $83.30 | $210.30 | $210.30
10 | $365.12 | $146.70 | $180.59 | $692.41 | $69.24
100 | $3030.60 | $671.60 | $1498.92 | $5201.12 | $52.01
500 | $13943.90 | $2616.90 | $6896.58 | $23457.38 | $46.91
1000 | $26626.00 | $5022.72 | $13169.08 | $44817.80 | $44.82

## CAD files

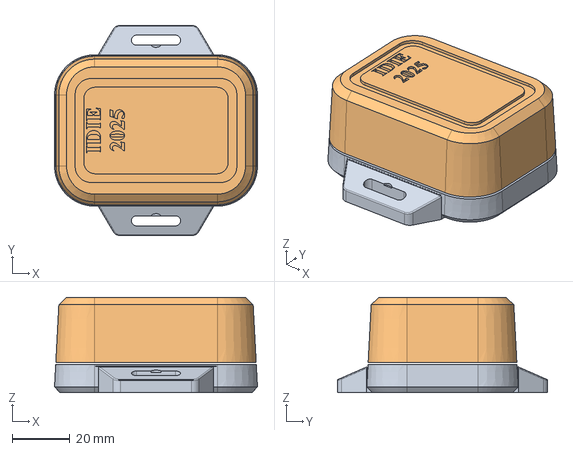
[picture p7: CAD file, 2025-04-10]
Documentos/Recapitulacion/Caja_IDIE.step
70.3 x 72.9 x 33.0 mm

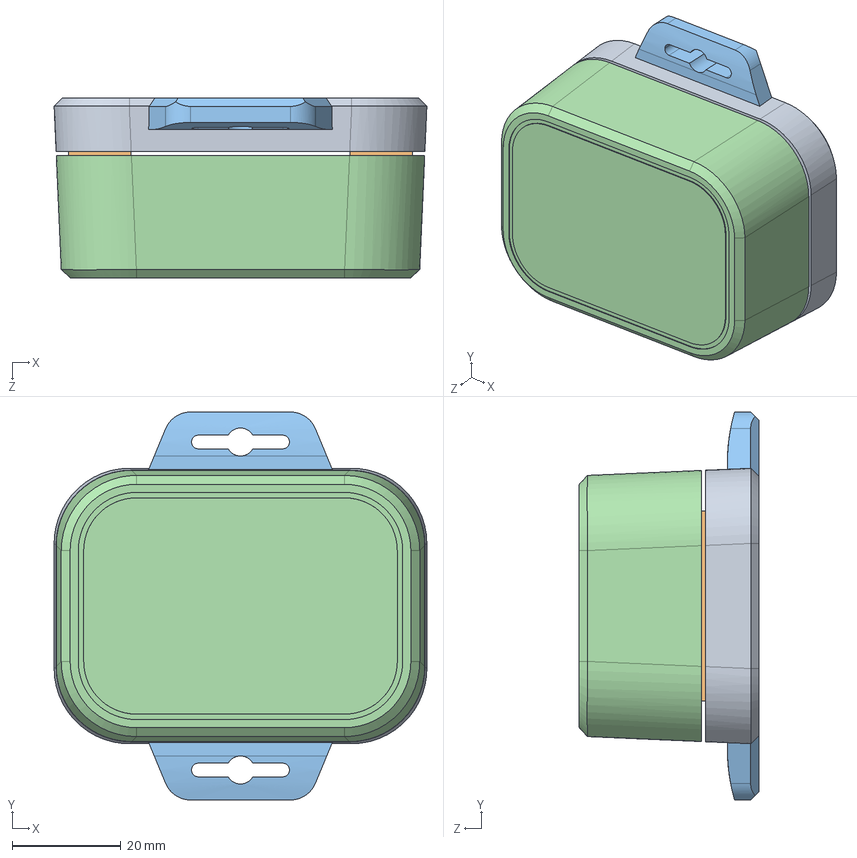
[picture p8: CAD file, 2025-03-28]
Documentos/Recapitulacion/S3L-272013.stp
68.6 x 71.4 x 33.0 mm

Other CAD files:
Documentos/Recapitulacion/caja_IDIE.stl

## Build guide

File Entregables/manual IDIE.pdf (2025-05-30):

# MANUAL USUARIO

## Sensor de vibración industrial con MQTT

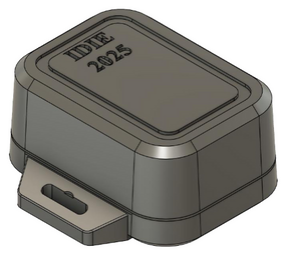
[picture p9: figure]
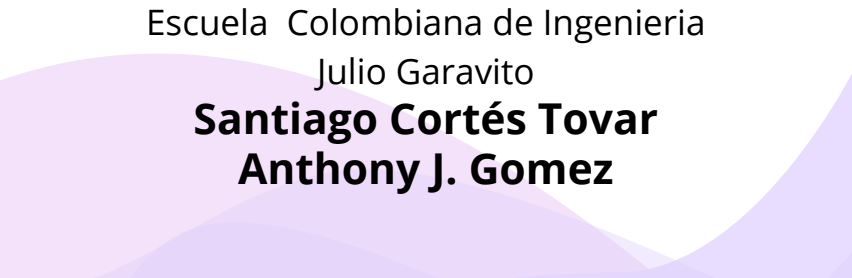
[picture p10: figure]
Santiago Cortés Tovar Anthony J. Gomez; Escuela Colombiana de Ingenieria Julio Garavito

# Contenido

### 1.Introducción |

### 1.1 Descripción de Producto | 1.2 Características Principales | 1.3 Contenido del Paquete |

### 2.Advertencias de Uso |

2.1 Condiciones Ambientales de Operación ........ 2.2 Seguridad Eléctrica y Manejo de Batería .......

### 2.3 Manipulación Física del Dispositivo |

### 3.Especificaciones Técnicas |

### 3.1 Características Físicas | 3.2 Caracteristicas Operativas |

### 4.Instalación Rápida |

4.1 Montaje del Dispositivo en la Maquinaria .... 4.2 Primer Encendido y Verificación de Estado...

### 5.Configuración Básica |

### 5.1 Conexión LoRa | 5.2 Ajuste de Parametros |

### 6.Integración Aplicaciones MQTT |

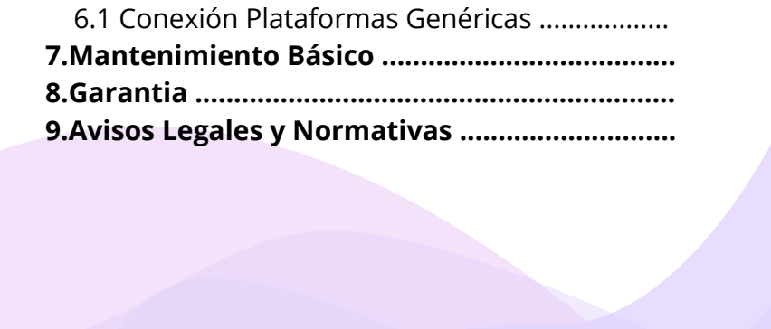
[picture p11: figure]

### 6.1 Conexión Plataformas Genéricas |

### 7.Mantenimiento Básico | 8.Garantia | 9.Avisos Legales y Normativas |

## 1.Introducción

El Dispositivo IoT de Monitoreo de Vibración de Maquinaria es una solución tecnológica avanzada diseñada para la supervisión continua y en tiempo real de la vibración en equipos industriales. Su propósito es facilitar el mantenimiento predictivo al permitir la detección temprana de anomalías, lo que contribuye a optimizar el rendimiento y prolongar la vida útil de la maquinaria crítica.
Este dispositivo se presenta en un formato compacto y robusto, protegido por una carcasa de plástico duradero (como ABS o PLA). Sus dimensiones finales, incluyendo la caja, no exceden los 100x100x60 milímetros, lo que asegura una fácil integración en diversos entornos industriales.

### 1.1 Descripción de Producto

### 1.2 Características Principales

El Dispositivo IoT de Monitoreo de Vibración de Maquinaria ha sido diseñado con un enfoque en la fiabilidad, la eficiencia y la adaptabilidad a entornos industriales exigentes. Sus características principales son:
Sensado de Vibración Triaxial de Alta Precisión: Equipado con un sensor de vibración capaz de medir movimientos en los tres ejes espaciales (X, Y y Z).
Conectividad LoRaWAN para Envío de Datos en Tiempo Real: La integración de la tecnología LoRaWAN (Long Range Wide Area Network) asegura una comunicación inalámbrica de bajo consumo y largo alcance. El dispositivo utiliza la banda AU915 Clase A para enviar los datos de vibración, nivel de batería y temperatura de forma periódica y en tiempo real.
Operación con Batería de Larga Duración (Mínimo 1 Año): Una de las ventajas más significativas del dispositivo es su autonomía energética. Está optimizado para funcionar con batería por un mínimo de un año, con reportes cada 15 minutos. Diseñado para Uso Industrial: El dispositivo está concebido para resistir las condiciones típicas de los entornos industriales. Se presenta ensamblado en su propia caja de plástico tipo ABS, PLA, etc., que no supera las dimensiones de 100x100x60 milímetros. Esta construcción robusta y compacta facilita su montaje directo en la maquinaria, garantizando su durabilidad y desempeño en ambientes exigentes como fábricas, plantas de producción y otras instalaciones industriales.

### 1.3 Contenido del Paquete

Al adquirir su Dispositivo IoT de Monitoreo de Vibración de Maquinaria, asegúrese de que la caja contiene los siguientes elementos:
La carcasa externa del equipo, fabricada en plástico duradero. Esta caja puede tener el diseño para resistencia IP en cualquiera de sus categorias dependiendo de la necesidad del usuario y de elementos extra a lo que tiene la caja.

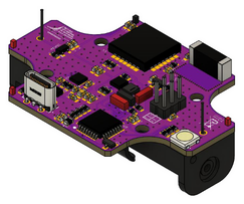
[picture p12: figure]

Se refiere a la unidad de monitoreo de vibración completamente ensamblada y programada o abierta a la programación que quiera el usuario.

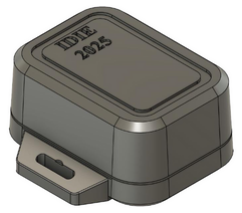
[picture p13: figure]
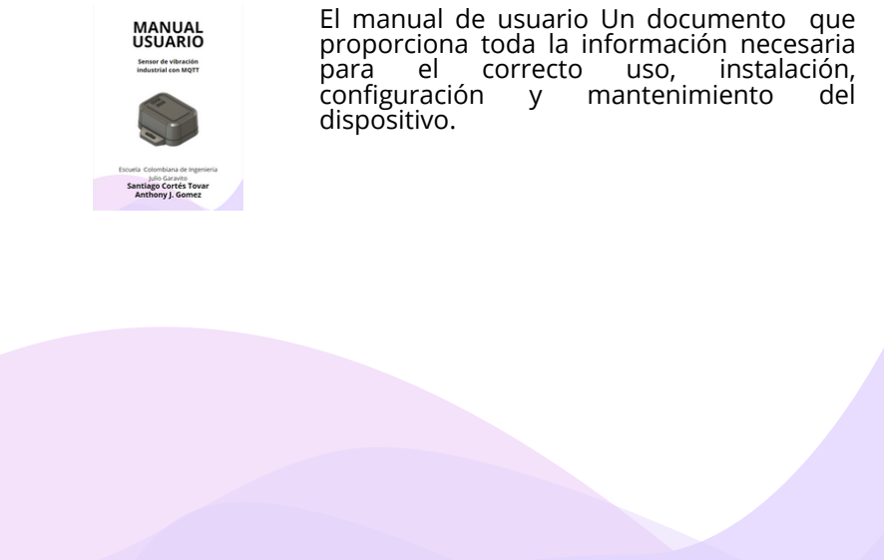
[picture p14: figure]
El manual de usuario Un documento que proporciona toda la información necesaria; para; correcto; uso,; instalación,; configuración; mantenimiento; del; dispositivo.

## 2.Advertencias de Uso

Para garantizar el funcionamiento óptimo y la durabilidad de su Dispositivo IoT de Monitoreo de Vibración de Maquinaria, es fundamental que se instale y opere dentro de las condiciones
ambientales | especificadas. | El | incumplimiento | de | estas
recomendaciones puede afectar el rendimiento del dispositivo, reducir su vida útil o causar daños permanentes.
Temperatura de Operación: El dispositivo está diseñado para funcionar en un rango de temperatura industrial como son -20°C a 80°C. Tenga precaución con su uso, si al excederse de los limites no ve cambios de operación, igualmente comuníquese a soporte técnico.
Humedad: Evite la exposición directa a líquidos, lluvia o niveles excesivos de humedad. Aunque la carcasa ofrece cierta protección, el dispositivo no es sumergible a menos que se especifique una certificación IP adicional. La humedad puede provocar cortocircuitos o corrosión de los componentes internos. Vibraciones Externas Excesivas: Aunque el dispositivo mide vibraciones, su correcto funcionamiento depende de un montaje estable en el punto de interés. Evite instalarlo en ubicaciones donde esté expuesto a vibraciones externas excesivas o golpes que no correspondan a la maquinaria que se desea monitorear, ya que esto podría comprometer la integridad física del dispositivo o la precisión de sus mediciones.
Campos Electromagnéticos (CEM): Procure instalar el dispositivo alejado de fuentes potentes de interferencia

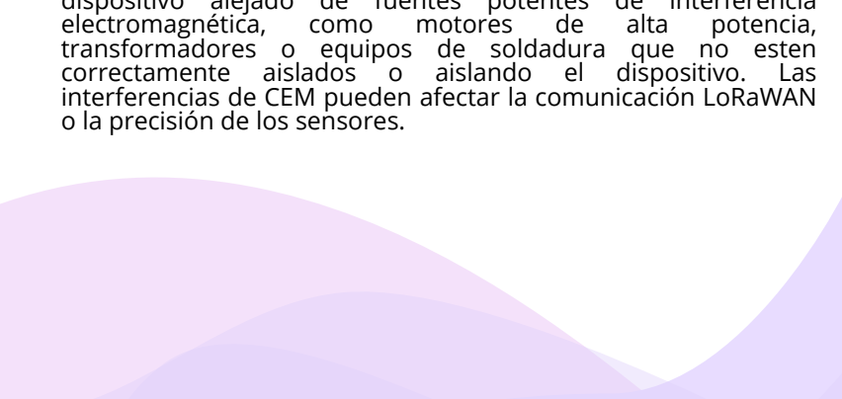
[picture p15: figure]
electromagnética,; como; motores; alta; potencia,; o la precisión de los sensores.

transformadores o equipos de soldadura que no esten correctamente aislados o aislando el dispositivo. Las interferencias de CEM pueden afectar la comunicación LoRaWAN

### 2.1 Condiciones Ambientales de Operación

### 2.2 Seguridad Eléctrica y Manejo de Batería

El Dispositivo IoT de Monitoreo de Vibración de Maquinaria opera con batería y ha sido diseñado para un bajo consumo energético. Sin embargo, es crucial observar las siguientes precauciones para garantizar la seguridad eléctrica y la correcta manipulación de la batería, evitando riesgos para el usuario y el dispositivo.
Fuente de Alimentación: Este dispositivo está diseñado para operar exclusivamente con la batería interna suministrada o una de sus especificaciones exactas. No intente alimentar el dispositivo con fuentes de energía externas o adaptadores no aprobados por el fabricante. El uso de fuentes de alimentación incorrectas puede dañar los circuitos internos y anular la garantía. Manejo de la Batería:
1.No perforar, aplastar o incinerar: Las baterías dañadas o expuestas a calor excesivo pueden incendiarse o explotar. 2.Evitar cortocircuitos: No cortocircuite los terminales de la batería. Esto puede generar calor excesivo, chispas o fuego, y dañar la batería o el dispositivo.
3.Reemplazo de la Batería : Aunque el dispositivo está diseñado para una autonomía de al menos un año, si es necesario reemplazar la batería, asegúrese de utilizar únicamente el tipo y modelo especificado por el fabricante. La sustitución incorrecta o el uso de baterías no compatibles pueden presentar riesgos de seguridad.
4.Descarte Responsable: Deseche las baterías usadas de acuerdo con las normativas locales y ambientales. Las baterías contienen sustancias que pueden ser perjudiciales si no se gestionan adecuadamente.
No Abrir el Dispositivo: La carcasa del dispositivo no está diseñada para ser abierta por el usuario. Intentar abrir el dispositivo puede exponerlo a componentes eléctricos, anular la garantía y dañar el equipo. Cualquier reparación o mantenimiento interno debe ser realizado únicamente por personal técnico cualificado.
Limpieza: Para la limpieza del dispositivo, desconéctelo de cualquier fuente de alimentación externa (si aplica) y utilice un paño seco y suave. No utilice líquidos, aerosoles o disolventes, ya que pueden filtrarse y dañar los componentes internos.

### 2.3 Manipulación Física del Dispositivo

El diseño del dispositivo tiene una carcasa que protege el dispositivo y mantiene el dispositivo protegido y listo para quedar bien anclado, sin embargo.
Evitar Golpes y Caídas: No está diseñado para soportar impactos severos o caídas desde alturas considerables. Un golpe fuerte puede dañar los componentes internos, incluyendo el sensor de vibración, la batería o las conexiones electrónicas, comprometiendo su precisión y funcionalidad.
No Aplicar Fuerza Excesiva: Al instalar o desinstalar el dispositivo, no aplique fuerza excesiva que pueda deformar la carcasa, los puntos de montaje o dañar los conectores. Asegúrese de que el montaje se realice de manera segura pero sin forzar ninguna parte del equipo.
Limpieza Adecuada: Para limpiar la superficie exterior del dispositivo, utilice un paño suave y seco. Evite el uso de productos químicos abrasivos, disolventes o limpiadores líquidos directamente sobre el dispositivo, ya que podrían dañar el material de la carcasa o infiltrarse en el interior.
Protección contra la Exposición Directa: Evite la exposición prolongada y directa a la luz solar intensa o a fuentes de calor radiante extremo, ya que esto podría afectar el material de la carcasa y la temperatura interna del dispositivo, impactando en la vida útil de la batería y la precisión de los sensores. Almacenamiento: Cuando el dispositivo no esté en uso, guárdelo en un lugar seco, fresco y seguro, lejos de vibraciones excesivas o de agentes corrosivos. Si va a ser almacenado por un periodo prolongado, asegúrese de seguir las recomendaciones del fabricante para el almacenamiento de la batería.

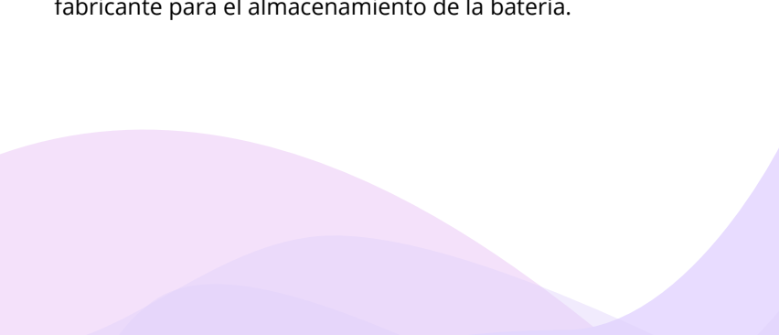
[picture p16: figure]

## 3.Especificaciones Técnicas

Esta sección detalla las características técnicas y los rangos de operación del Dispositivo IoT de Monitoreo de Vibración de Maquinaria, proporcionando una referencia clara sobre sus capacidades y limitaciones.

## 3.1 Características Físicas

Funcionalidad Principal: Medición de vibración de maquinaria en 3 ejes (X-Y-Z).
Datos Reportados por Eje: Vibración máxima detectada, promedio de vibración, desviación estándar, nivel de batería y temperatura del dispositivo.
Conectividad: LoRaWAN en la banda AU915 Clase A.
Protocolo de Visualización: MQTT para integración con aplicaciones móviles estándar.
Autonomía de Batería: Mínimo 1 año con reportes cada 15 minutos.
Dimensiones Físicas (Máx.): 100x100x60 milímetros (dispositivo final en su caja).
Herramientas de Configuración: Permite configurar banda de operación, canales, modo de registro a la red LoRaWAN, claves, tiempo de reporte.

### 3.2 Caracteristicas Operativas

Rango de Temperatura: El dispositivo reposrta su temperatura de operación para evitar fallos en medidas ademas de alertar por problemas.
Período de Reporte: Configurable, con un mínimo predeterminado de cada 15 minutos.
Banda de Frecuencia: El dispositivo opera en la banda AU915. Es fundamental que la infraestructura de red LoRaWAN (gateways) en el área de operación sea compatible con esta banda.

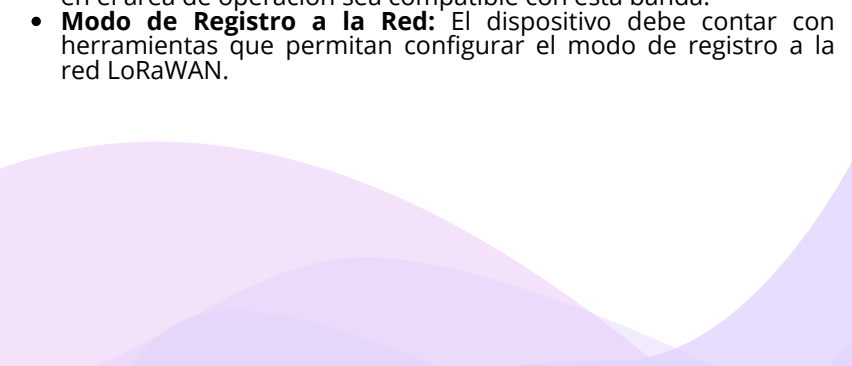
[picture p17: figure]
red LoRaWAN.

Modo de Registro a la Red: El dispositivo debe contar con herramientas que permitan configurar el modo de registro a la

## 4.Instalación Rápida

Esta sección proporciona una guía concisa para la instalación inicial y el primer encendido de su Dispositivo IoT de Monitoreo de Vibración de Maquinaria. Para una configuración más detallada, consulte las secciones de "Configuración Básica" y "Configuración de Dashboards".

### 4.1 Montaje del Dispositivo en la Maquinaria

El montaje adecuado del dispositivo es crucial para asegurar mediciones de vibración precisas y consistentes.
1.Selección de la Ubicación: Identifique un punto en la maquinaria que sea representativo de la vibración que desea monitorear. La superficie debe ser lo más plana y estable posible para asegurar un contacto firme.
2.Preparación de la Superficie: Limpie la superficie de montaje de cualquier suciedad, grasa, óxido o pintura suelta. Una superficie limpia y seca es esencial para una adhesión o fijación óptima. 3.Fijación del Dispositivo: Utilice los materiales de montaje provistos (si aplica) o los recomendados para fijar firmemente el dispositivo a la maquinaria. Asegúrese de que el dispositivo esté bien sujeto y no tenga juego, ya que cualquier movimiento del dispositivo no relacionado con la vibración de la máquina afectará la precisión de las mediciones. Verifique que la orientación del dispositivo sea la deseada para los ejes X, Y y Z, si es relevante para su análisis de vibración específico.

### 4.2 Primer Encendido y Verificación de Estado

Una vez que el dispositivo esté montado de forma segura, siga estos pasos para el primer encendido:
1.Activación: El dispositivo debería encenderse automáticamente una vez que la batería esté conectada (si no viene pre-conectada) o si se realiza la activación inicial según el diseño específico del hardware.
2.Indicadores de Estado (si aplica): Observe cualquier indicador LED en el dispositivo. Estos indicadores suelen proporcionar información sobre el estado de encendido, el estado de la batería y la conectividad LoRaWAN. Consulte la sección de "Solución de Problemas" o "Especificaciones Técnicas" para el significado de los diferentes patrones de luz.
3.Verificación de Conectividad LoRaWAN: El dispositivo intentará conectarse a la red LoRaWAN en la banda AU915. Este proceso puede tardar unos minutos. Una vez conectado, el dispositivo comenzará a enviar reportes periódicos de vibración, nivel de batería y temperatura.
4.Confirmación en la Plataforma: Acceda a su aplicación móvil o dashboard configurado con MQTT para verificar que el dispositivo está reportando datos correctamente. Debería ver los primeros datos de vibración (máxima, promedio, desviación estándar por eje), nivel de batería y temperatura.

## 5.Configuración Básica

Esta sección describe cómo configurar los parámetros esenciales de su Dispositivo IoT de Monitoreo de Vibración de Maquinaria para asegurar su correcta operación y comunicación con la red LoRaWAN. El dispositivo cuenta con herramientas que permiten ajustar estos parámetros.

### 5.1. Conexión LoRaWAN

Para que el dispositivo se comunique correctamente con la red LoRaWAN, es necesario configurar los parámetros de conexión. Herramienta de Configuración: Utilice la herramienta de configuración provista (software o interfaz específica) para acceder a los ajustes del dispositivo. La forma de acceso puede variar (por ejemplo, a través de una conexión USB, Bluetooth, o una interfaz de programación específica). Consulte la documentación adjunta a la herramienta para instrucciones detalladas sobre su uso.
Selección de Banda de Operación: Confirme que la banda de operación esté configurada en AU915, de acuerdo con la banda de frecuencia LoRaWAN utilizada en su región y por su proveedor de red.
Configuración de Canales de Operación: Ajuste los canales de operación LoRaWAN según los requisitos de su red. Su proveedor de servicios LoRaWAN o administrador de red le proporcionará la información necesaria sobre los canales activos.
Modo de Registro a la Red LoRaWAN: El dispositivo debe soportar modos de registro como OTAA (Over-The-Air Activation) o ABP (Activation by Personalization).
OTAA (Recomendado): Este modo es el más seguro y flexible. Requiere que configure las siguientes claves en el dispositivo y en su servidor de red LoRaWAN:
DevEUI: (Identificador único del dispositivo)
AppEUI: (Identificador de la aplicación)
AppKey: (Clave de aplicación) Asegúrese de que estas claves coincidan exactamente en el dispositivo y en la plataforma de su proveedor LoRaWAN para permitir la activación.
ABP: Este modo utiliza un conjunto preestablecido de claves que se programan directamente en el dispositivo y el servidor de red. Es menos seguro y menos flexible que OTAA, pero puede ser útil en escenarios específicos. Las claves a configurar son:
DevAddr: (Dirección del dispositivo)
NwkSKey: (Clave de sesión de red)
AppSKey: (Clave de sesión de aplicación)

## 6. Integración con aplicaciones MQTT

Esta sección describe cómo conectar el dispositivo a plataformas IoT mediante el protocolo MQTT, permitiendo la visualización remota de datos de vibración, batería y temperatura en tiempo real.

### 6.1. Conexión con Plataformas Genéricas

El dispositivo está diseñado para integrarse con plataformas IoT que soporten el protocolo MQTT (como ThingsBoard, Node-RED, The Things Stack, entre otras). A continuación se describen los pasos generales para realizar la integración:
Requisitos Previos:
Tener acceso a una red LoRaWAN compatible y funcional. Configurar correctamente el gateway y la red LoRaWAN para reenviar los datos al broker MQTT.
Disponer de un broker MQTT (público o privado).
Parámetros de conexión MQTT comunes:
Servidor (Broker): IP o dominio del servidor MQTT.
Puerto: Típicamente 1883 (sin cifrado) o 8883 (con TLS/SSL). Usuario/Contraseña: Si se requiere autenticación.
Topico MQTT: Generalmente tiene esta forma: vibration/{DevEUI}/data
Formato de datos: JSON
Dashboards y Visualización:
Utiliza dashboards como los de ThingsBoard, Ubidots, o una interfaz propia en Node-RED para visualizar los datos.
Se recomienda configurar alertas ante desviaciones en los

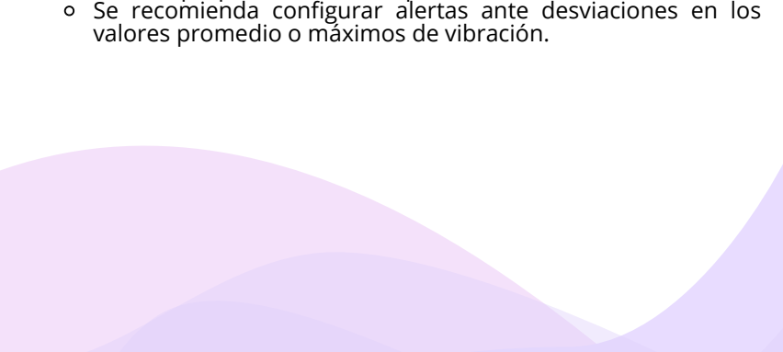
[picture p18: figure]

valores promedio o máximos de vibración.

## 7. Mantenimiento Básico

El mantenimiento del Dispositivo IoT de Monitoreo de Vibración de Maquinaria debe realizarse de forma preventiva y periódica para asegurar un funcionamiento confiable y prolongado. Aunque el diseño del sistema está optimizado para operar sin intervención durante al menos un año, se recomienda seguir las siguientes pautas:

Revisión Periódica
Cada 6 meses: realizar una inspección visual del estado físico del dispositivo, asegurando que esté firmemente montado, sin signos de daño, corrosión, o suciedad excesiva.
Estado de la batería: monitorear desde la plataforma de recepción MQTT si el voltaje reportado de la batería cae por debajo del umbral operativo recomendado (típicamente 2.5V).
Limpieza
Utilizar un paño seco o ligeramente humedecido (sin solventes) para remover polvo o residuos adheridos a la carcasa.
No abrir el dispositivo ni aplicar líquidos directamente. Sustitución de la batería
Una vez que el voltaje sea inferior al mínimo operativo, debe sustituirse la batería con una del mismo modelo especificado

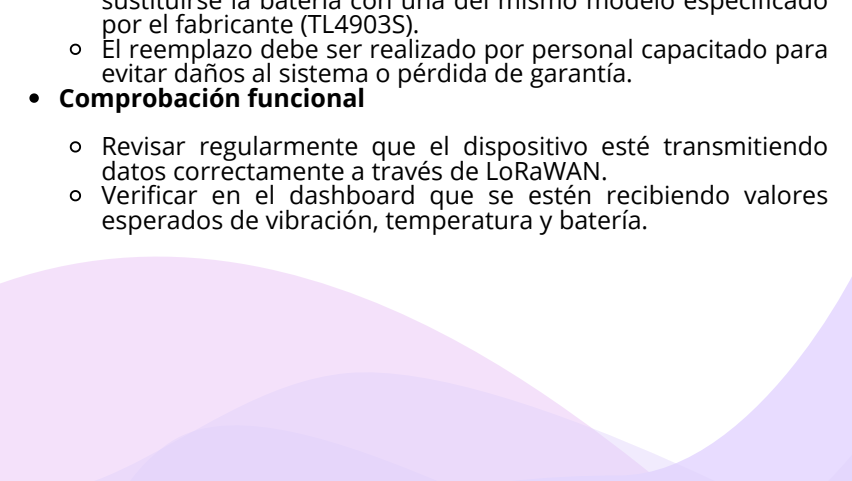
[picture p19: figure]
por el fabricante (TL4903S).; Comprobación funcional

El reemplazo debe ser realizado por personal capacitado para evitar daños al sistema o pérdida de garantía.

Revisar regularmente que el dispositivo esté transmitiendo datos correctamente a través de LoRaWAN.
Verificar en el dashboard que se estén recibiendo valores esperados de vibración, temperatura y batería.

## 8. Garantía

El Dispositivo IoT de Monitoreo de Vibración de Maquinaria cuenta con una garantía limitada ofrecida por el fabricante, válida durante 12 meses a partir de la fecha de entrega del producto, cubriendo exclusivamente defectos de fabricación y funcionamiento bajo condiciones normales de uso.

Cobertura de la garantía
Fallos del microcontrolador, sensor triaxial, módulo LoRaWAN u otros componentes internos bajo uso correcto.
Problemas de ensamblaje o fabricación que afecten el desempeño del dispositivo.
Exclusiones
La garantía no aplica en los siguientes casos:
Manipulación física inapropiada o daños mecánicos por caídas, golpes, o exposición a líquidos.
Uso del dispositivo fuera de los rangos especificados de temperatura, humedad o voltaje.
Instalación, apertura o modificación del hardware por parte de terceros no autorizados.
Uso de baterías incompatibles o no autorizadas.
Trámite de garantía
Para reportar un incidente cubierto por la garantía, el usuario debe: Contactar al proveedor o soporte técnico oficial.

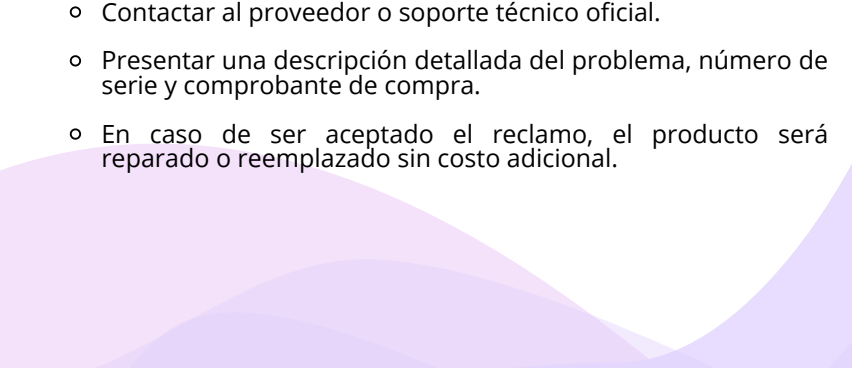
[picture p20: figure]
serie y comprobante de compra.

Presentar una descripción detallada del problema, número de

En caso de ser aceptado el reclamo, el producto será reparado o reemplazado sin costo adicional.

## 9. Avisos legales y normativas

Este dispositivo ha sido diseñado para cumplir con los estándares técnicos y ambientales necesarios para su uso en aplicaciones industriales bajo el marco normativo colombiano e internacional. Normativas aplicables
Operación en banda AU915 autorizada para redes LoRaWAN en América del Sur.
Restricción de sustancias peligrosas conforme a la directiva RoHS: el dispositivo está libre de plomo y materiales prohibidos.
Cumplimiento de buenas prácticas de diseño electrónico para minimizar interferencias electromagnéticas (EMI).
Uso responsable
El dispositivo está destinado exclusivamente para monitoreo de vibraciones en maquinaria industrial.
Cualquier modificación, uso fuera del propósito previsto o integración inadecuada puede invalidar su funcionamiento y

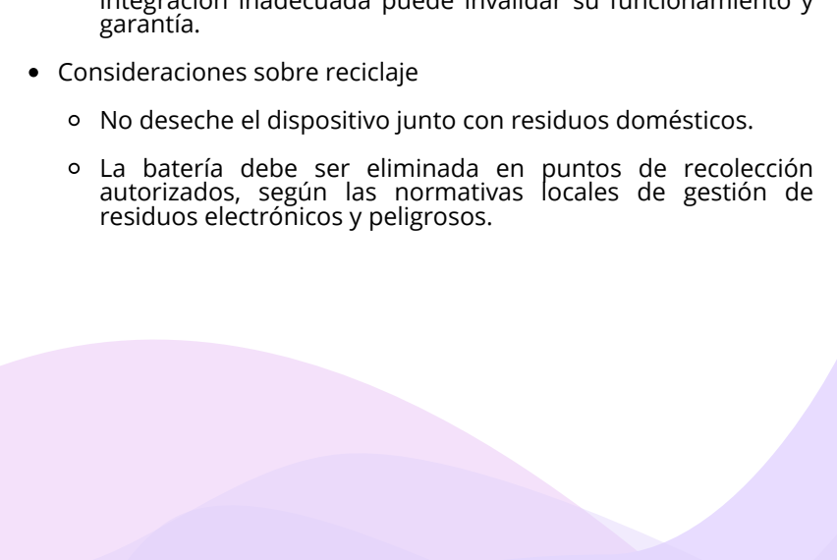
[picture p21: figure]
garantía.; Consideraciones sobre reciclaje; residuos electrónicos y peligrosos.

No deseche el dispositivo junto con residuos domésticos.
La batería debe ser eliminada en puntos de recolección autorizados, según las normativas locales de gestión de

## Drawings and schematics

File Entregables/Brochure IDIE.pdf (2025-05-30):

# MEDIDOR DE VIBRACIÓN

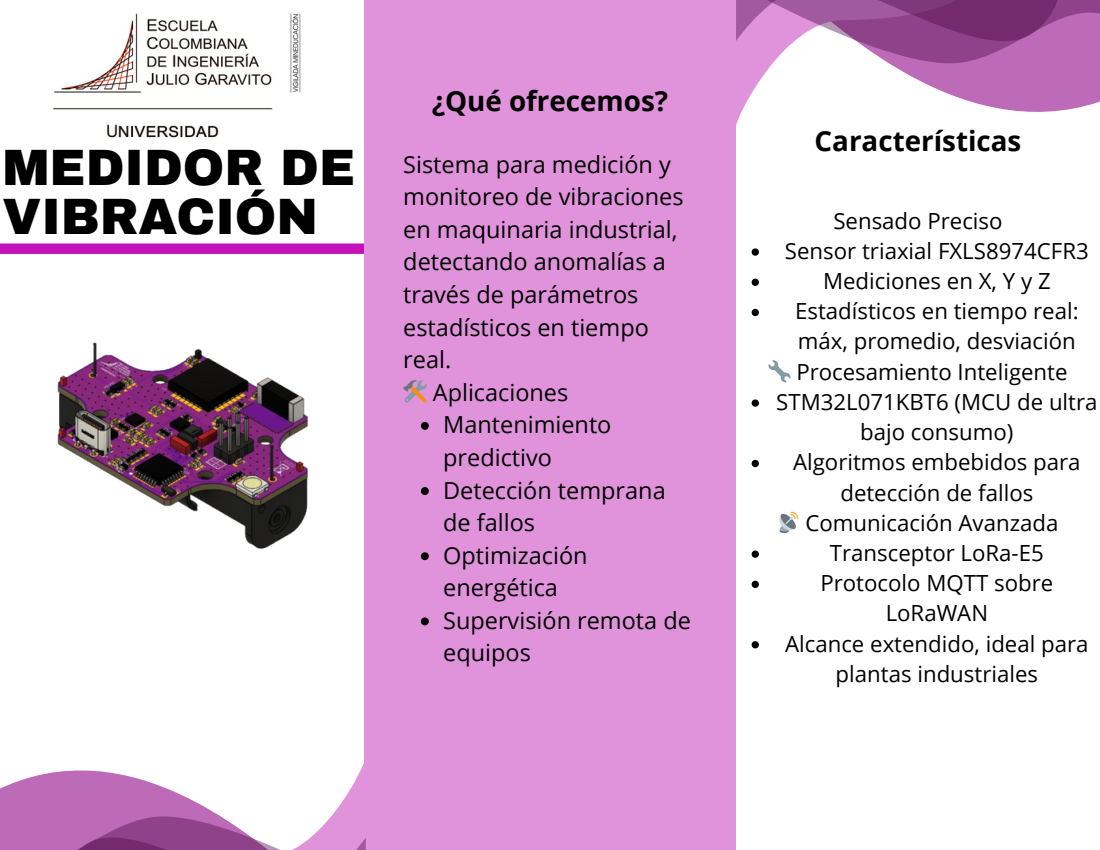
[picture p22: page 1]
¿Qué ofrecemos?; Características

Sistema para medición y
monitoreo de vibraciones
en maquinaria industrial,
detectando anomalías a
través de parámetros
estadísticos en tiempo
real.
️ Aplicaciones
Mantenimiento
predictivo
Detección temprana
de fallos
Optimización
energética
Supervisión remota de
equipos

Sensado Preciso
Sensor triaxial FXLS8974CFR3
Mediciones en X, Y y Z
Estadísticos en tiempo real:
máx, promedio, desviación
🔧 Procesamiento Inteligente
STM32L071KBT6 (MCU de ultra
bajo consumo)
Algoritmos embebidos para
detección de fallos
📡 Comunicación Avanzada
Transceptor LoRa-E5
Protocolo MQTT sobre
LoRaWAN

Alcance extendido, ideal para
plantas industriales

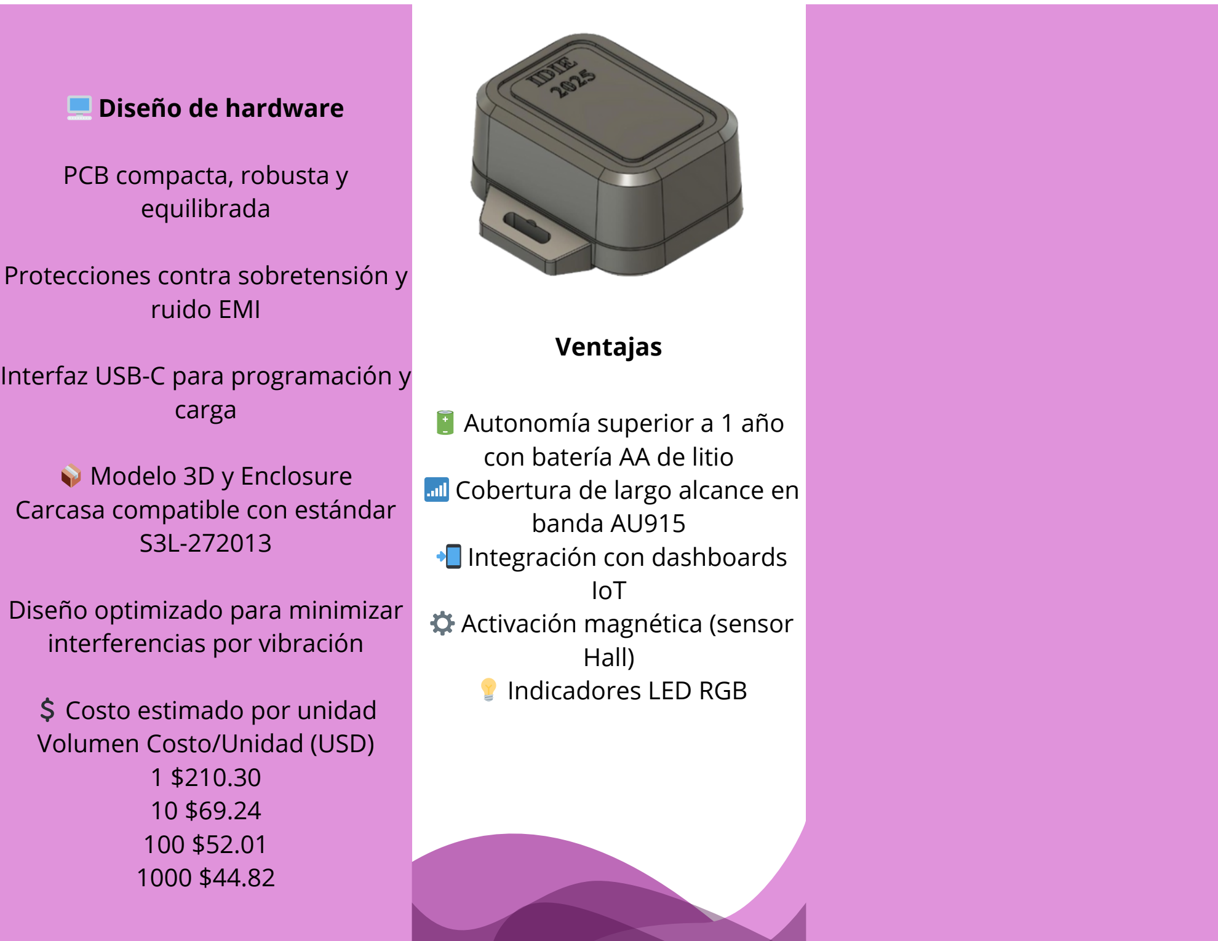
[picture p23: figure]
️ Diseño de hardware; PCB compacta, robusta y equilibrada; Protecciones contra sobretensión y ruido EMI; Interfaz USB-C para programación y carga; 📦 Modelo 3D y Enclosure Carcasa compatible con estándar S3L-272013; Diseño optimizado para minimizar interferencias por vibración; 💲 Costo estimado por unidad Volumen Costo/Unidad (USD) 1 $210.30 10 $69.24 100 $52.01 1000 $44.82; 🔋 Autonomía superior a 1 año con batería AA de litio 📶 Cobertura de largo alcance en banda AU915 📲 Integración con dashboards IoT ⚙️ Activación magnética (sensor Hall) 💡 Indicadores LED RGB; Ventajas

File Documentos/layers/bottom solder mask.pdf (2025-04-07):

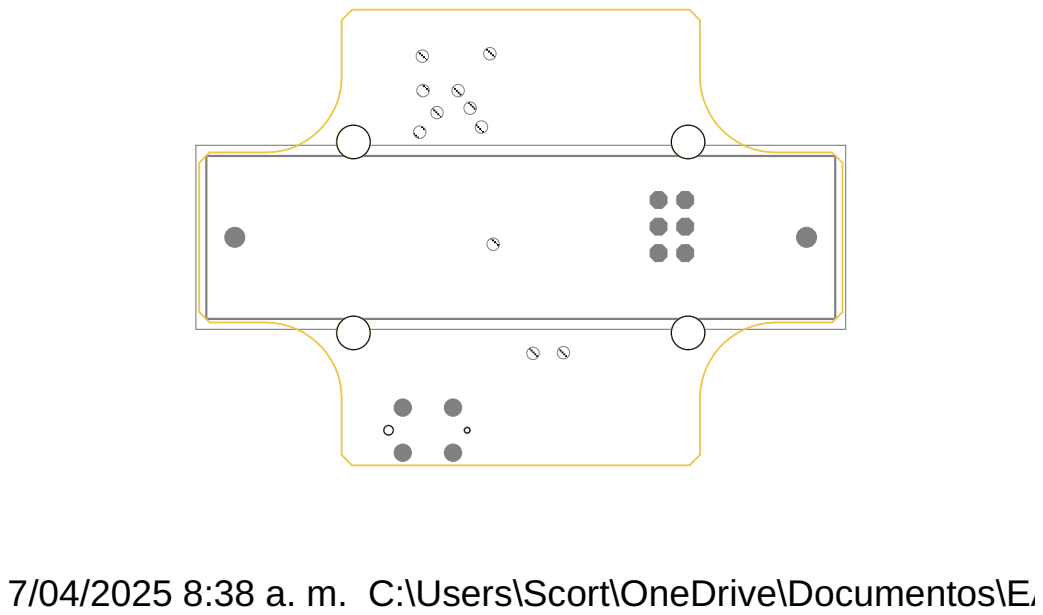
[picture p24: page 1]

7/04/2025 8:38 a. m. C:\Users\Scort\OneDrive\Documentos\EAGLE\projects\IDIE\vibration_sensor_pcb.brd

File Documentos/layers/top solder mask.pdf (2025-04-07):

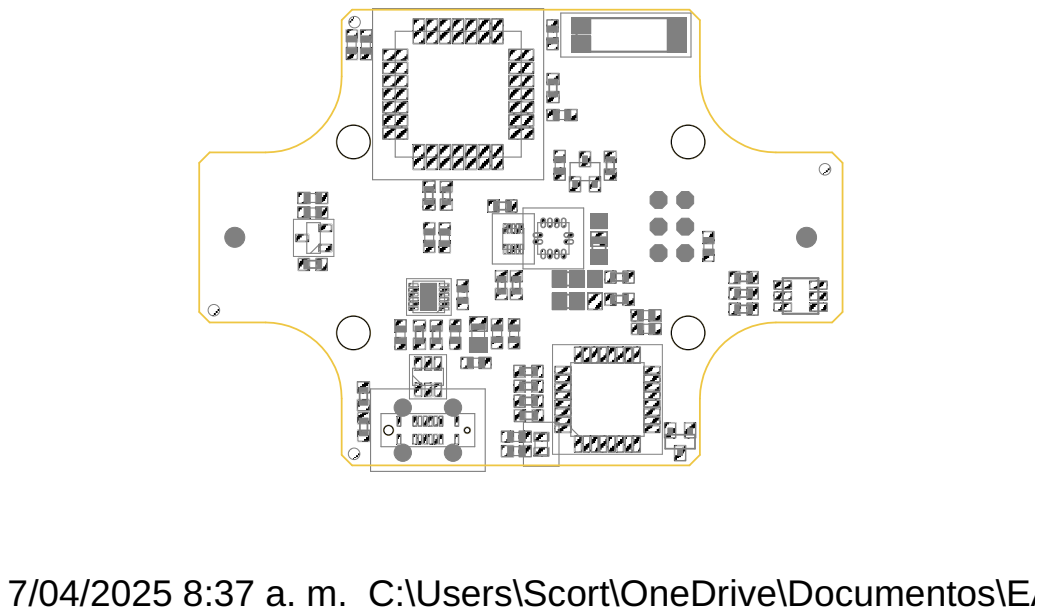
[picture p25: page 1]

7/04/2025 8:37 a. m. C:\Users\Scort\OneDrive\Documentos\EAGLE\projects\IDIE\vibration_sensor_pcb.brd

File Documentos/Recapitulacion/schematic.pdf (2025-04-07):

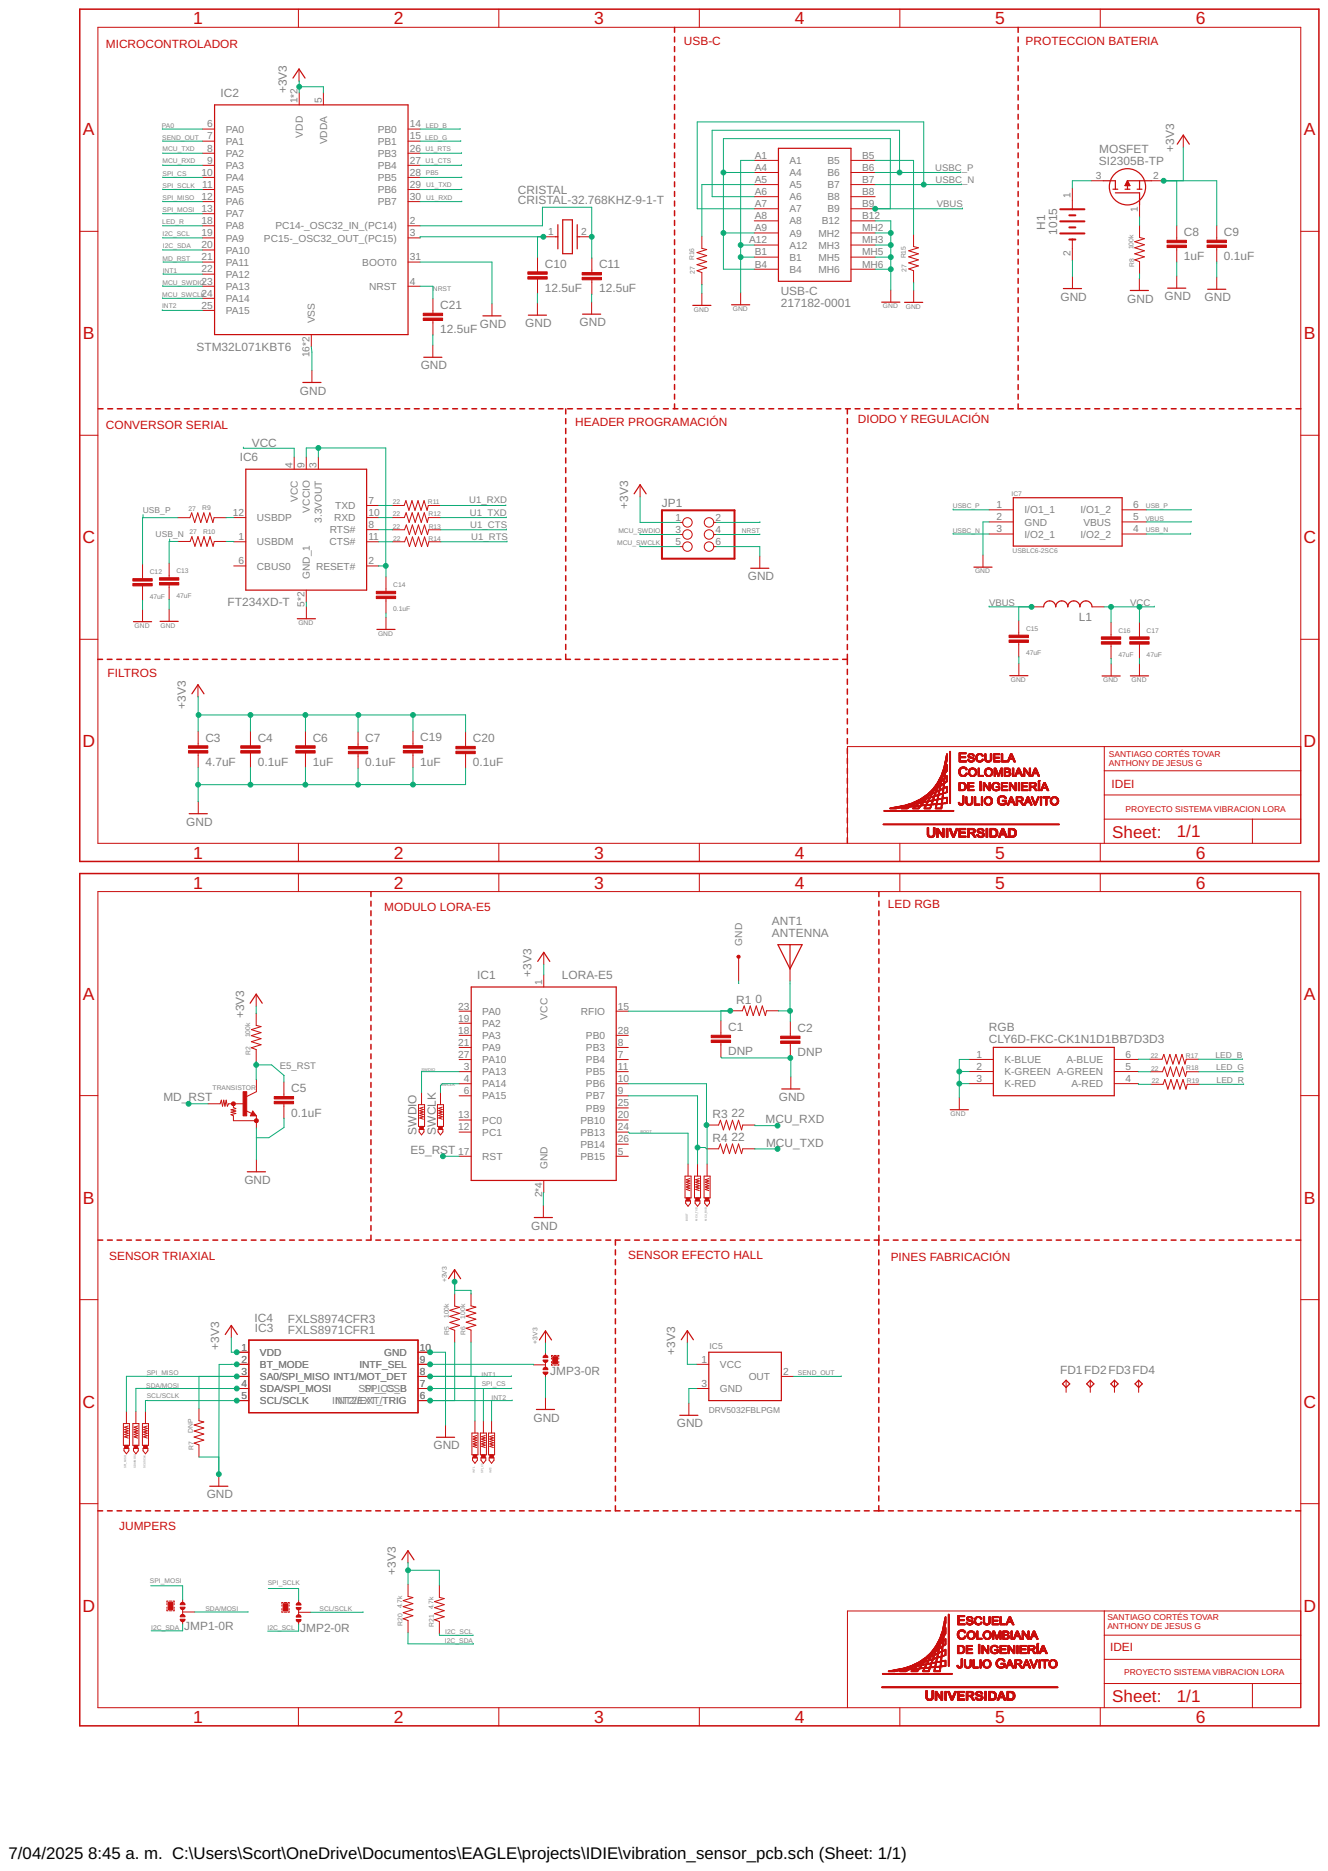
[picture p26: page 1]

IDEI SANTIAGO CORTÉS TOVAR
ANTHONY DE JESUS G

PROYECTO SISTEMA VIBRACION LORA
Sheet:

SDA/MOSI SCL/SCLK

7/04/2025 8:45 a. m. C:\Users\Scort\OneDrive\Documentos\EAGLE\projects\IDIE\vibration_sensor_pcb.sch (Sheet: 1/1)

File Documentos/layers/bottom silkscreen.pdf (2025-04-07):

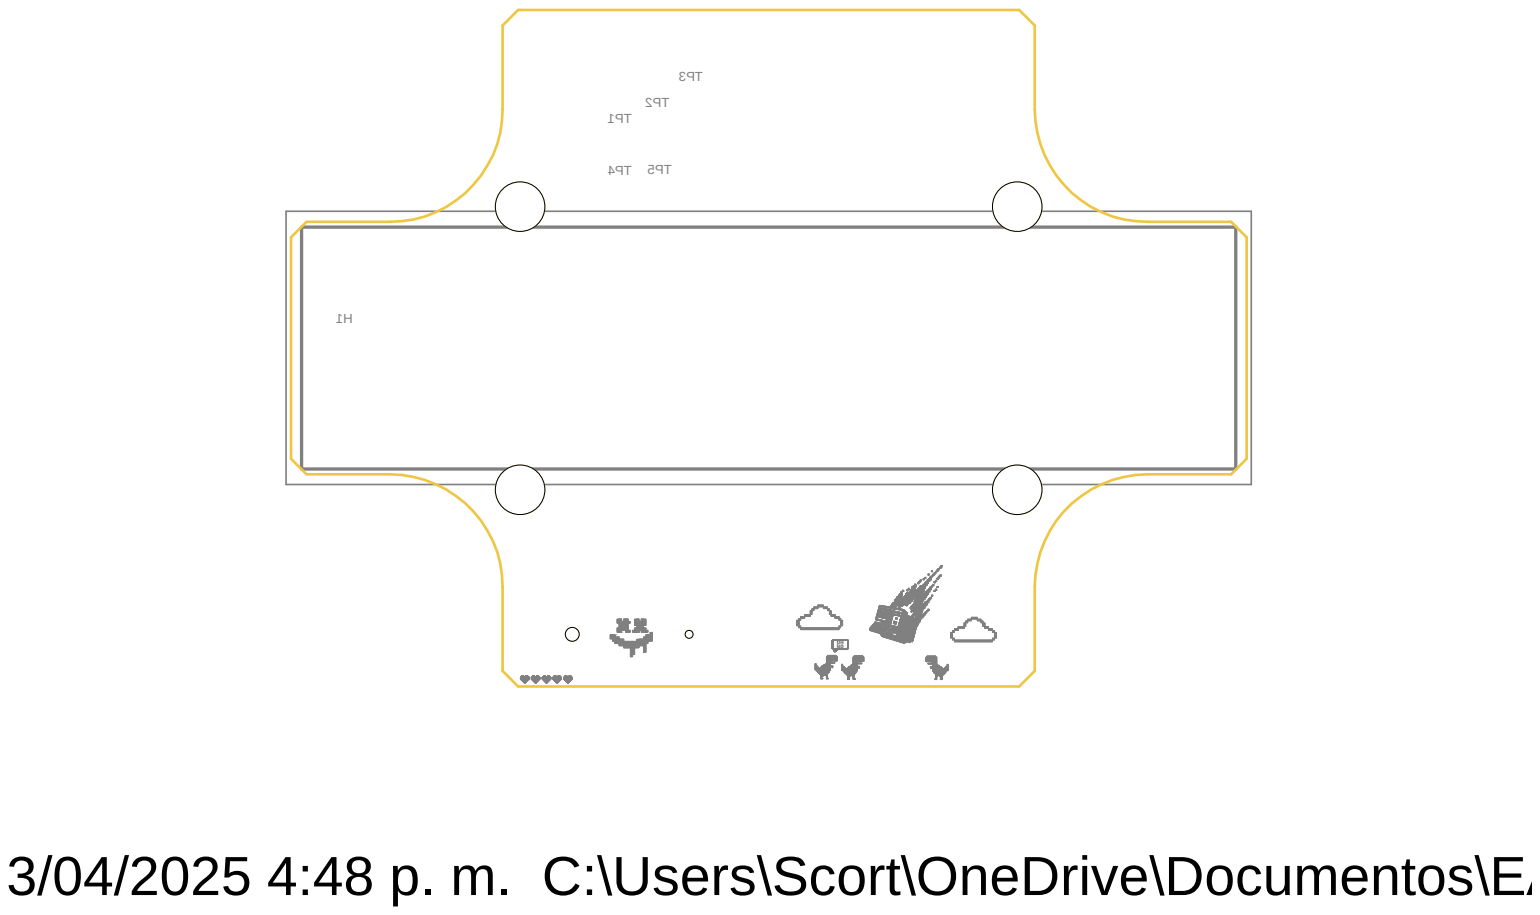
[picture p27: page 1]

3/04/2025 4:48 p. m. C:\Users\Scort\OneDrive\Documentos\EAGLE\projects\IDIE\vibration_sensor_pcb.brd

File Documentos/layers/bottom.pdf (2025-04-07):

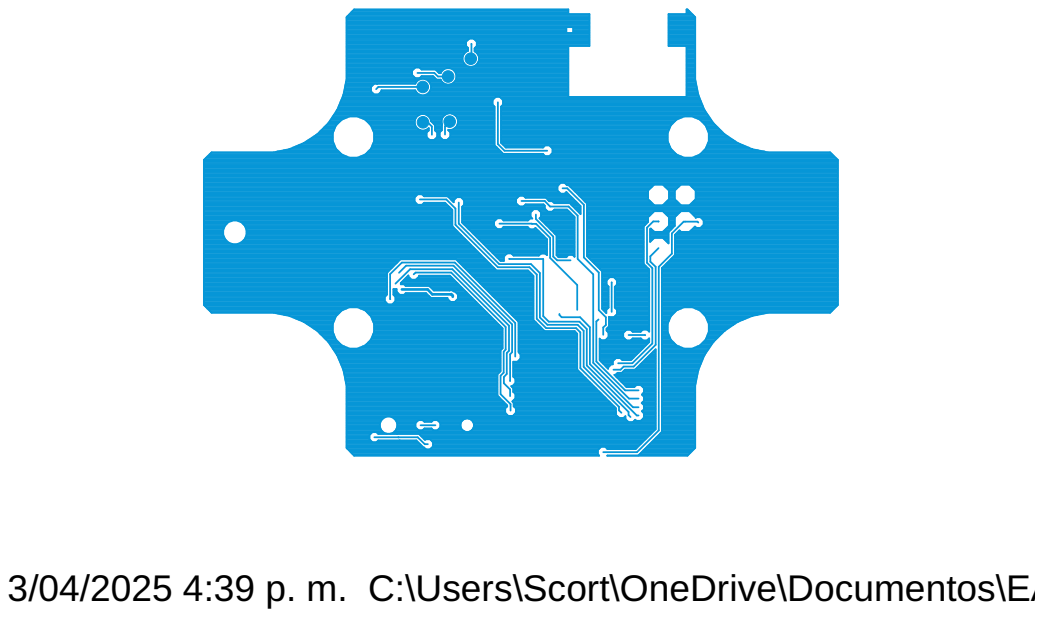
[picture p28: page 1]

3/04/2025 4:39 p. m. C:\Users\Scort\OneDrive\Documentos\EAGLE\projects\IDIE\vibration_sensor_pcb.brd

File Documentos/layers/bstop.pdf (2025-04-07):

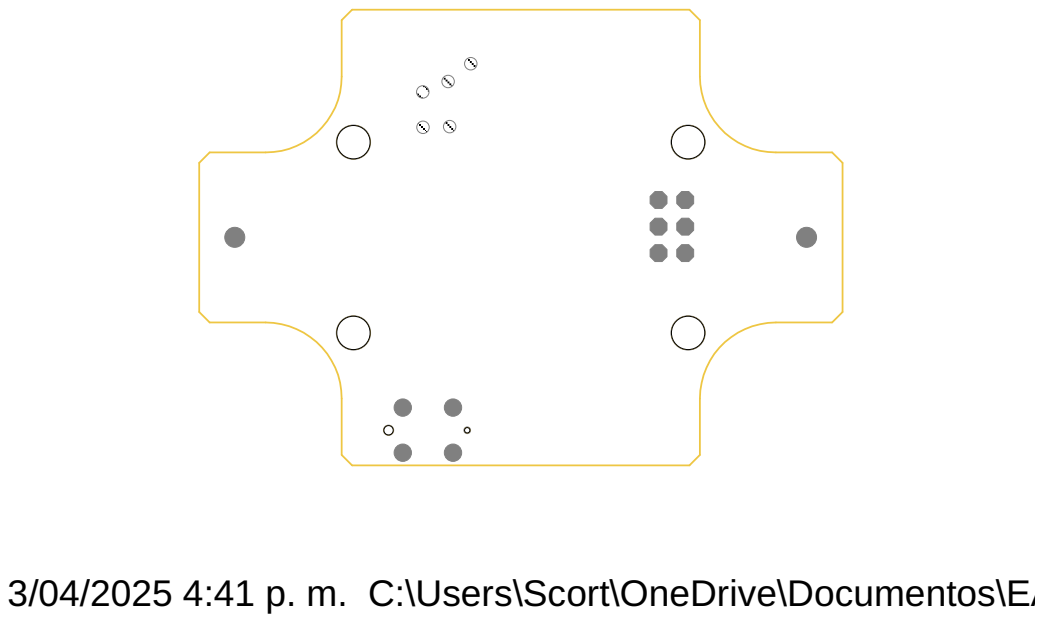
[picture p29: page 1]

3/04/2025 4:41 p. m. C:\Users\Scort\OneDrive\Documentos\EAGLE\projects\IDIE\vibration_sensor_pcb.brd

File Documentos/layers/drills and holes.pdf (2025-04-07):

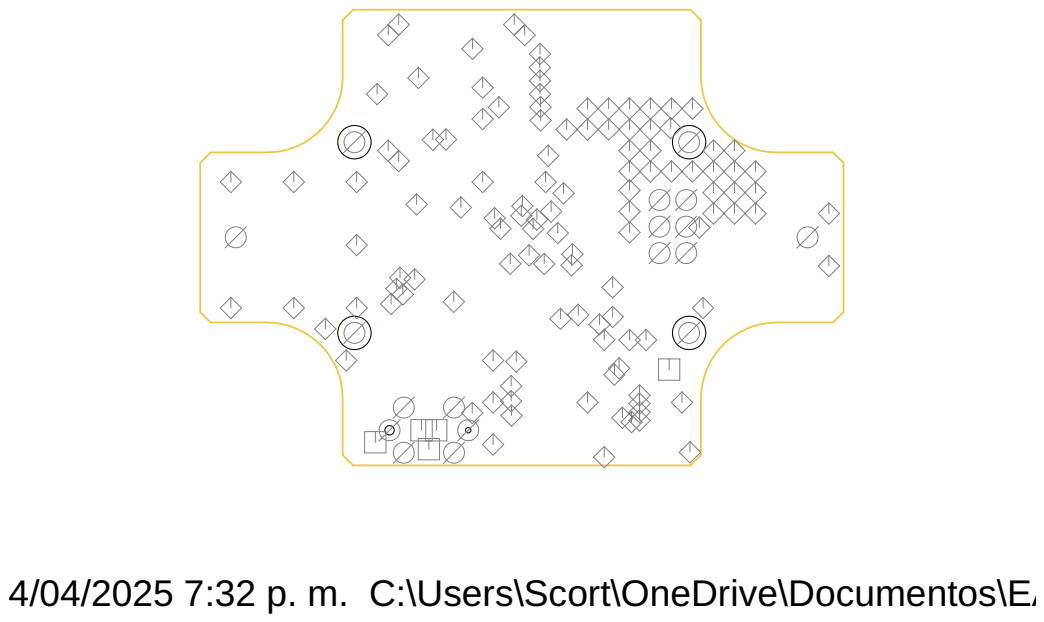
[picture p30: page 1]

4/04/2025 7:32 p. m. C:\Users\Scort\OneDrive\Documentos\EAGLE\projects\IDIE\vibration_sensor_pcb.brd

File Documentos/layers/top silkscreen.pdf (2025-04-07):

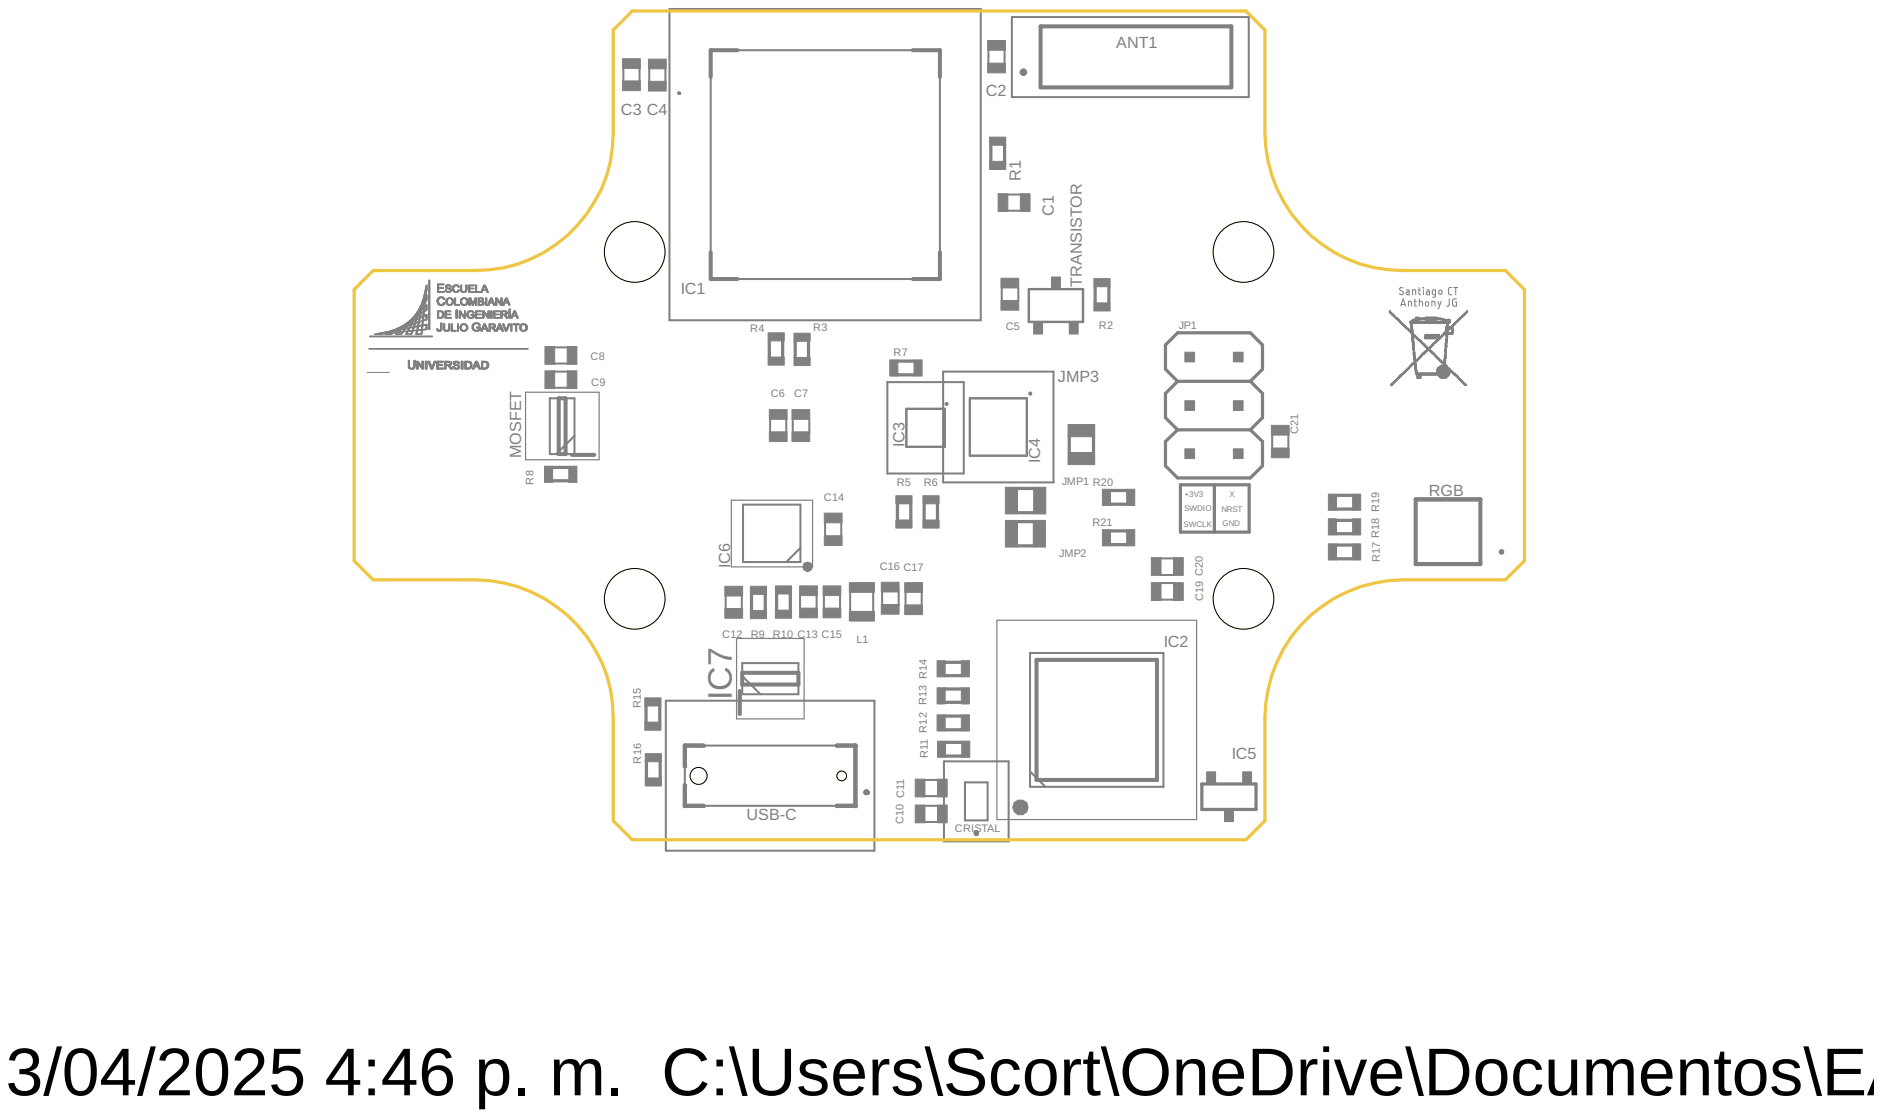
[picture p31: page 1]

3/04/2025 4:46 p. m. C:\Users\Scort\OneDrive\Documentos\EAGLE\projects\IDIE\vibration_sensor_pcb.brd

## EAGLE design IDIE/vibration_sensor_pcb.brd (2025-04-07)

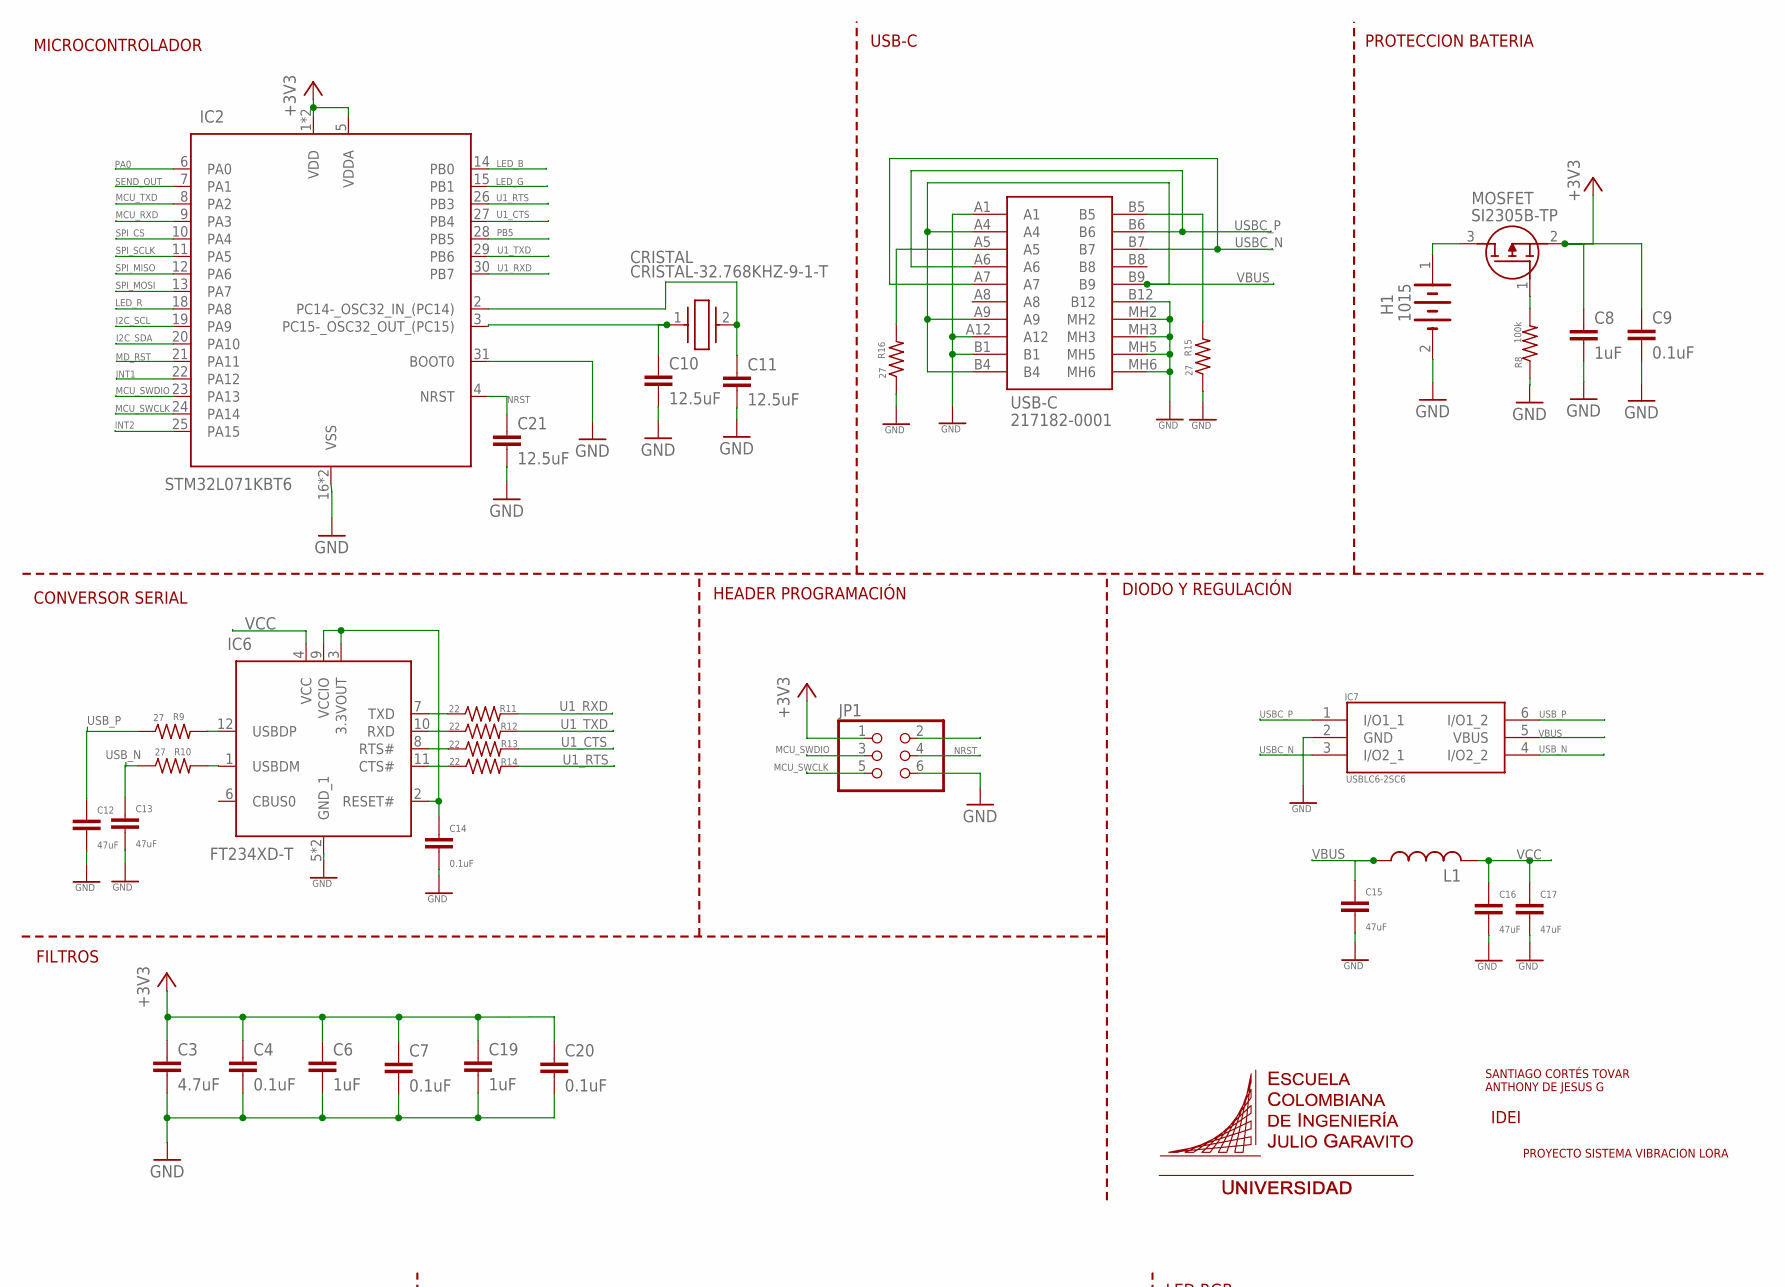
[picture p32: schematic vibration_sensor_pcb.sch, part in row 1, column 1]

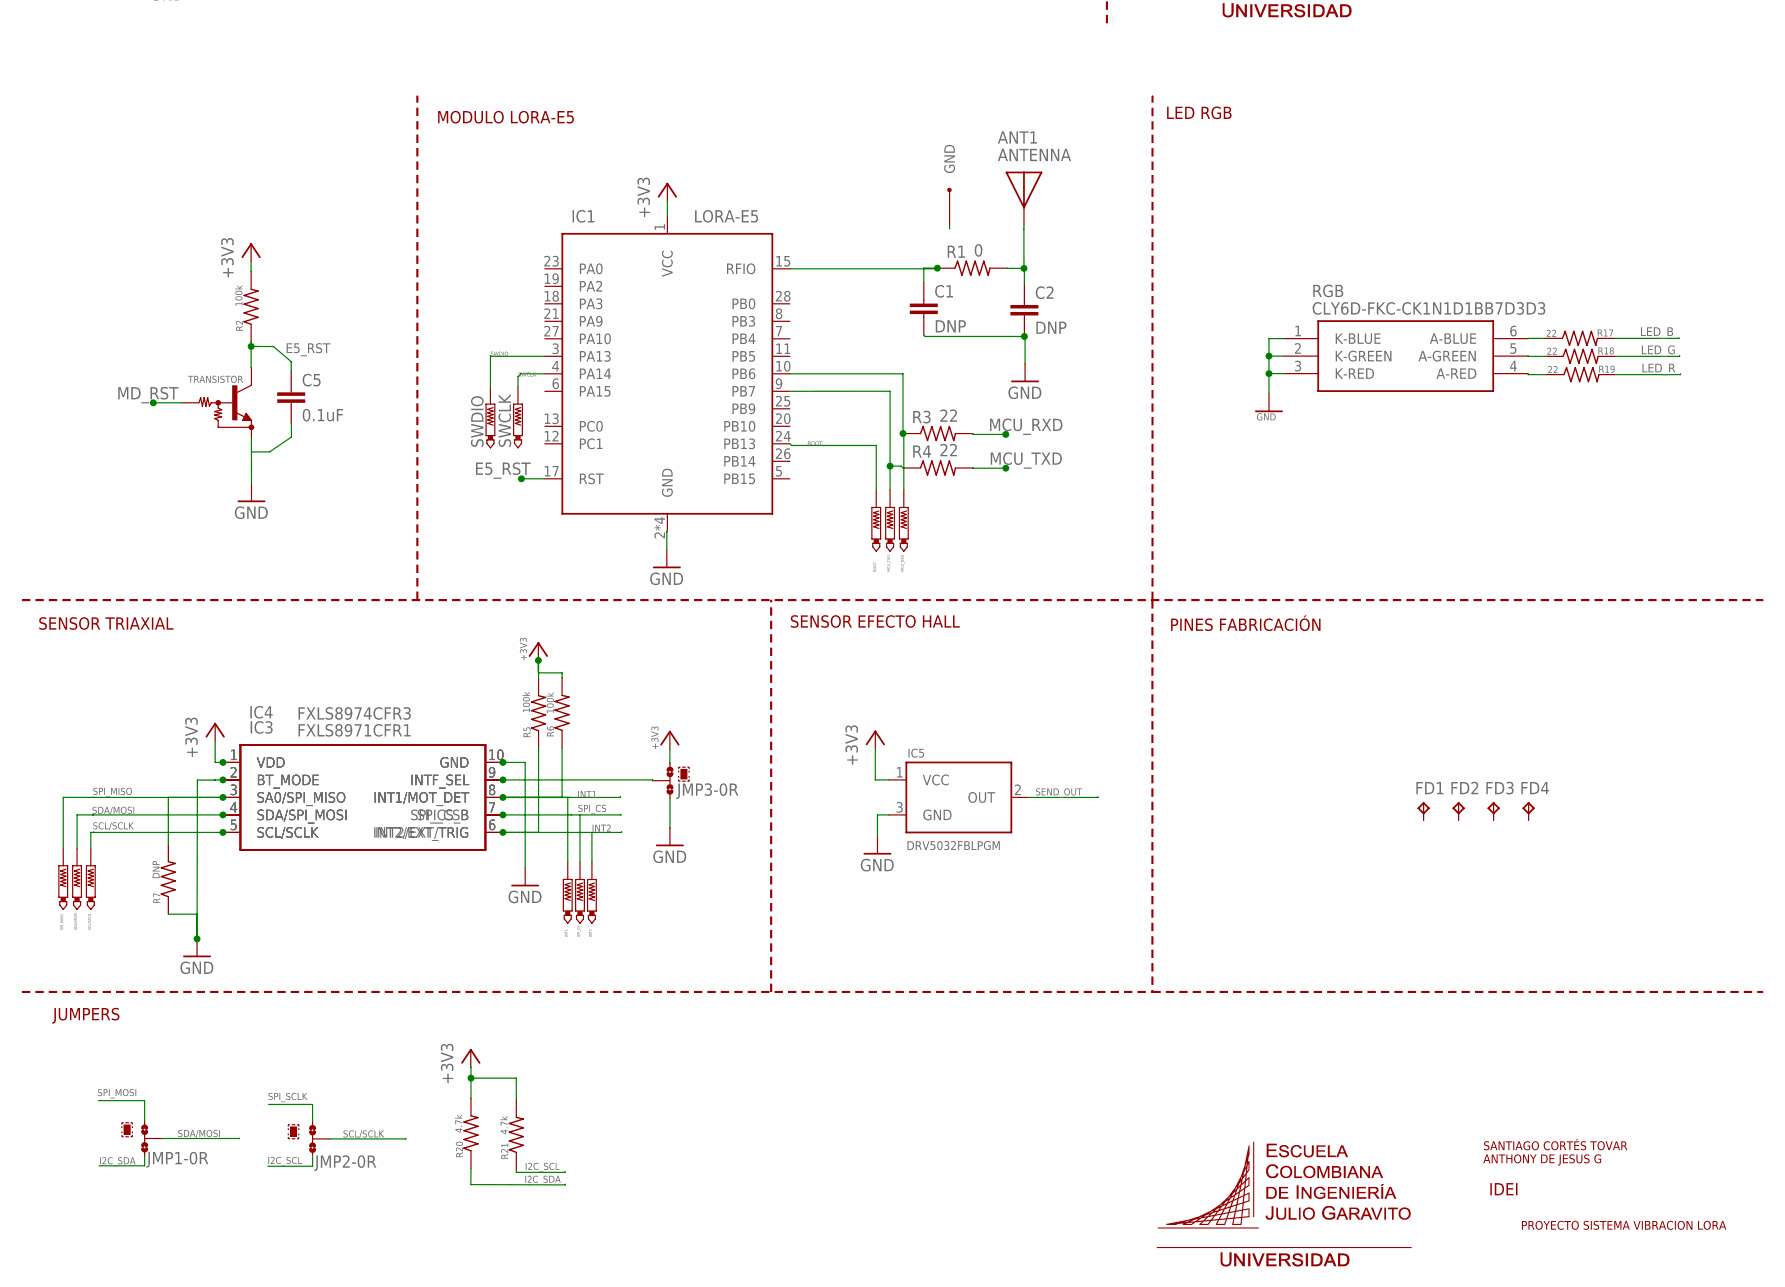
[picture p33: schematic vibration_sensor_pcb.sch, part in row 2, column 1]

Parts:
ANT1: ANTENNA
BOOT: PTR1TP11R; TP11R
C1, C2: DNP; C0603
C3: 4.7uF; C0603
C4, C5, C7, C9, C14, C20: 0.1uF; C0603
C6, C8, C19: 1uF; C0603
C10, C11, C21: 12.5uF; C0603
C12, C13, C15, C16, C17: 47uF; C0603
CRISTAL: CRISTAL-32.768KHZ-9-1-T; CRISTAL-32.768
FD1, FD2, FD3, FD4: TPTP10R; TP10R
H1: 1015
IC1: LORA-E5
IC2: STM32L071KBT6
IC3: FXLS8974CFR3
IC4: FXLS8971CFR1
IC5: DRV5032FBLPGM; SOT23
IC6: FT234XD-T; SON45P300X300X80-13N
IC7: USBLC6-2SC6; SOT95P280X145-6N
INT1, INT2: PTR1TP11R; TP11R
JMP1, JMP2, JMP3: 0R-JUMPA; A0R-JMP
JP1: PINHD-2X3; 2X03
L1: L-US; C0805K
MCU_RXD: PTR1TP11R; TP11R
MCU_TXD: PTR1TP11R; TP11R
MOSFET: SI2305B-TP; SOT95P237X125-3N
R1: 0; R0603
R2, R5, R6, R8: 100k; R0603
R3, R4, R11, R12, R13, R14, R17, R18, R19: 22; R0603
R7: DNP; R0603
R9, R10, R15, R16: 27; R0603
R20, R21: 4.7k; R0603
RGB: CLY6D-FKC-CK1N1D1BB7D3D3; PLCC6
SCL/SCLK: PTR1TP11R; TP11R
SDA/MOSI: PTR1TP11R; TP11R
SPI_CS: PTR1TP11R; TP11R
SPI_MISO: PTR1TP11R; TP11R
SWCLK: PTR1TP11R; TP11R
SWDIO: PTR1TP11R; TP11R
TRANSISTOR: MUN2211T1-NPN_DRIVER-SC59-BEC; SC59-BEC
USB-C: 217182-0001; 2171820001

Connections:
+3V3: C3.1, C4.1, C6.1, C7.1, C8.1, C9.1, C19.1, C20.1, IC1.1 (VCC), IC2.1 (VDD), IC2.5 (VDDA), IC2.17 (VDD), IC3.1 (VDD), IC4.1 (VDD), IC5.1 (VCC), JMP3.3, JP1.1, MOSFET.2 (S), R2.2, R5.2, R6.2, R20.2, R21.2
A5: R16.2, USB-C.A5
ANT: ANT1.1 (FEED), C2.1, R1.2
B5: R15.2, USB-C.B5
BOOT: BOOT.TP, IC1.24 (PB13)
E5_RST: C5.1, IC1.17 (RST), R2.1, TRANSISTOR.C
GATE: MOSFET.1 (G), R8.2
GND: ANT1.2 (GND), ANT1.3 (GND), C1.2, C2.2, C3.2, C4.2, C5.2, C6.2, C7.2, C8.2, C9.2, C10.2, C11.2, C12.2, C13.2, C14.2, C15.2, C16.2, C17.2, C19.2, C21.2, H1.2 (-), IC1.2 (GND), IC1.14 (GND), IC1.16 (GND), IC1.22 (GND), IC2.16 (VSS), IC2.31 (BOOT0), IC2.32 (VSS), IC3.2 (BT_MODE), IC3.10 (GND), IC4.2 (BT_MODE), IC4.10 (GND), IC5.3 (GND), IC6.5 (GND_1), IC6.13 (GND_1), IC7.2 (GND), JMP3.1, JP1.6, R7.1, R8.1, R15.1, R16.1, RGB.1 (K-BLUE), RGB.2 (K-GREEN), RGB.3 (K-RED), TRANSISTOR.E, USB-C.A1, USB-C.A12, USB-C.B1, USB-C.B12, USB-C.MH2, USB-C.MH3, USB-C.MH5, USB-C.MH6
GND1: C20.2
I2C_SCL: IC2.19 (PA9), JMP2.3, R21.1
I2C_SDA: IC2.20 (PA10), JMP1.3, R20.1
INT1: IC2.22 (PA12), IC3.8 (INT1/MOT_DET), IC4.8 (INT1/MOT_DET), INT1.TP, R6.1
INT2: IC2.25 (PA15), IC3.6 (INT2/EXT_TRIG), IC4.6 (INT2/EXT/TRIG), INT2.TP, R5.1
INTF_SEL: IC3.9 (INTF_SEL), IC4.9 (INTF_SEL), JMP3.2
IN_MOSFET: H1.1 (+), MOSFET.3 (D)
LED_B: IC2.14 (PB0), R17.2
LED_G: IC2.15 (PB1), R18.2
LED_R: IC2.18 (PA8), R19.2
LORA_RXD: IC1.10 (PB6), MCU_RXD.TP, R3.1
LORA_TXD: IC1.9 (PB7), MCU_TXD.TP, R4.1
MCU_RXD: IC2.9 (PA3), R3.2
MCU_SWCLK: IC2.24 (PA14), JP1.5
MCU_SWDIO: IC2.23 (PA13), JP1.3
MCU_TXD: IC2.8 (PA2), R4.2
MD_RST: IC2.21 (PA11), TRANSISTOR.B
NRST: C21.1, IC2.4 (NRST), JP1.4
OSC32_IN: C11.1, CRISTAL.2, IC2.2 (PC14-_OSC32_IN_(PC14))
OSC32_OUT: C10.1, CRISTAL.1, IC2.3 (PC15-_OSC32_OUT_(PC15))
OUT_ANT: C1.1, IC1.15 (RFIO), R1.1
PA0: IC2.6 (PA0)
PB5: IC2.28 (PB5)
R11: IC6.7 (TXD), R11.1
R12: IC6.10 (RXD), R12.1
R13: IC6.8 (RTS#), R13.1
R14: IC6.11 (CTS#), R14.1
R17: R17.1, RGB.6 (A-BLUE)
R18: R18.1, RGB.5 (A-GREEN)
R19: R19.1, RGB.4 (A-RED)
RESET#: C14.1, IC6.2 (RESET#), IC6.3 (3.3VOUT), IC6.9 (VCCIO)
SCL/SCLK: IC3.5 (SCL/SCLK), IC4.5 (SCL/SCLK), JMP2.2, SCL/SCLK.TP
SDA/MOSI: IC3.4 (SDA/SPI_MOSI), IC4.4 (SDA/SPI_MOSI), JMP1.2, SDA/MOSI.TP
SEND_OUT: IC2.7 (PA1), IC5.2 (OUT)
SPI_CS: IC2.10 (PA4), IC3.7 (SPI_CS_B), IC4.7 (SPI_CSB), SPI_CS.TP
SPI_MISO: IC2.12 (PA6), IC3.3 (SA0/SPI_MISO), IC4.3 (SA0/SPI_MISO), R7.2, SPI_MISO.TP
SPI_MOSI: IC2.13 (PA7), JMP1.1
SPI_SCLK: IC2.11 (PA5), JMP2.1
SWCLK: IC1.4 (PA14), SWCLK.TP
SWDIO: IC1.3 (PA13), SWDIO.TP
U1_CTS: IC2.27 (PB4), R13.2
U1_RTS: IC2.26 (PB3), R14.2
U1_RXD: IC2.30 (PB7), R11.2
U1_TXD: IC2.29 (PB6), R12.2
USBC_N: IC7.3 (I/O2_1), USB-C.A7, USB-C.B7
USBC_P: IC7.1 (I/O1_1), USB-C.A6, USB-C.B6
USBDM: IC6.1 (USBDM), R10.2
USBDP: IC6.12 (USBDP), R9.2
USB_N: C13.1, IC7.4 (I/O2_2), R10.1
USB_P: C12.1, IC7.6 (I/O1_2), R9.1
VBUS: C15.1, IC7.5 (VBUS), L1.1, USB-C.A4, USB-C.A9, USB-C.B4, USB-C.B9
VCC: C16.1, C17.1, IC6.4 (VCC), L1.2

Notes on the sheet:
IDEI
SANTIAGO CORTÉS TOVAR ANTHONY DE JESUS G
PROYECTO SISTEMA VIBRACION LORA
MICROCONTROLADOR
USB-C
PROTECCION BATERIA
CONVERSOR SERIAL
HEADER PROGRAMACIÓN
DIODO Y REGULACIÓN
MODULO LORA-E5
LED RGB
SENSOR TRIAXIAL
SENSOR EFECTO HALL
PINES FABRICACIÓN
JUMPERS
FILTROS

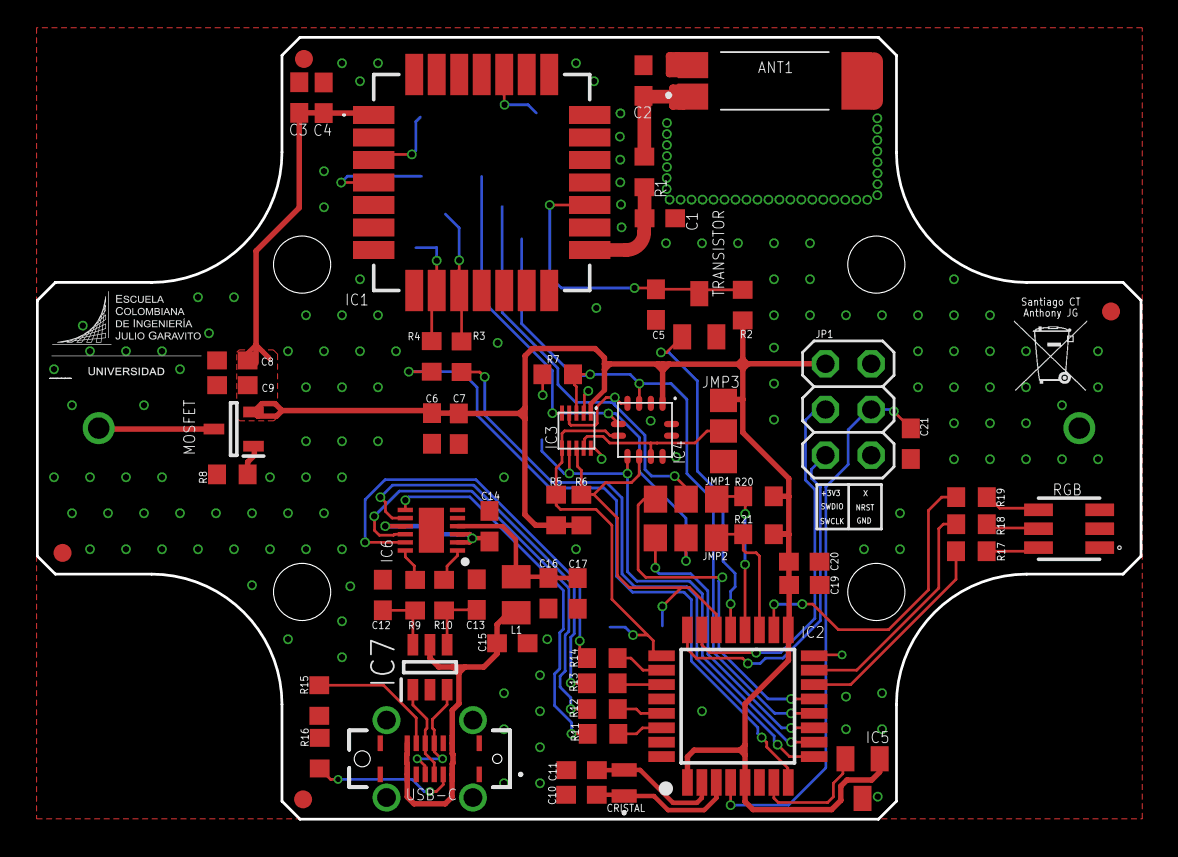
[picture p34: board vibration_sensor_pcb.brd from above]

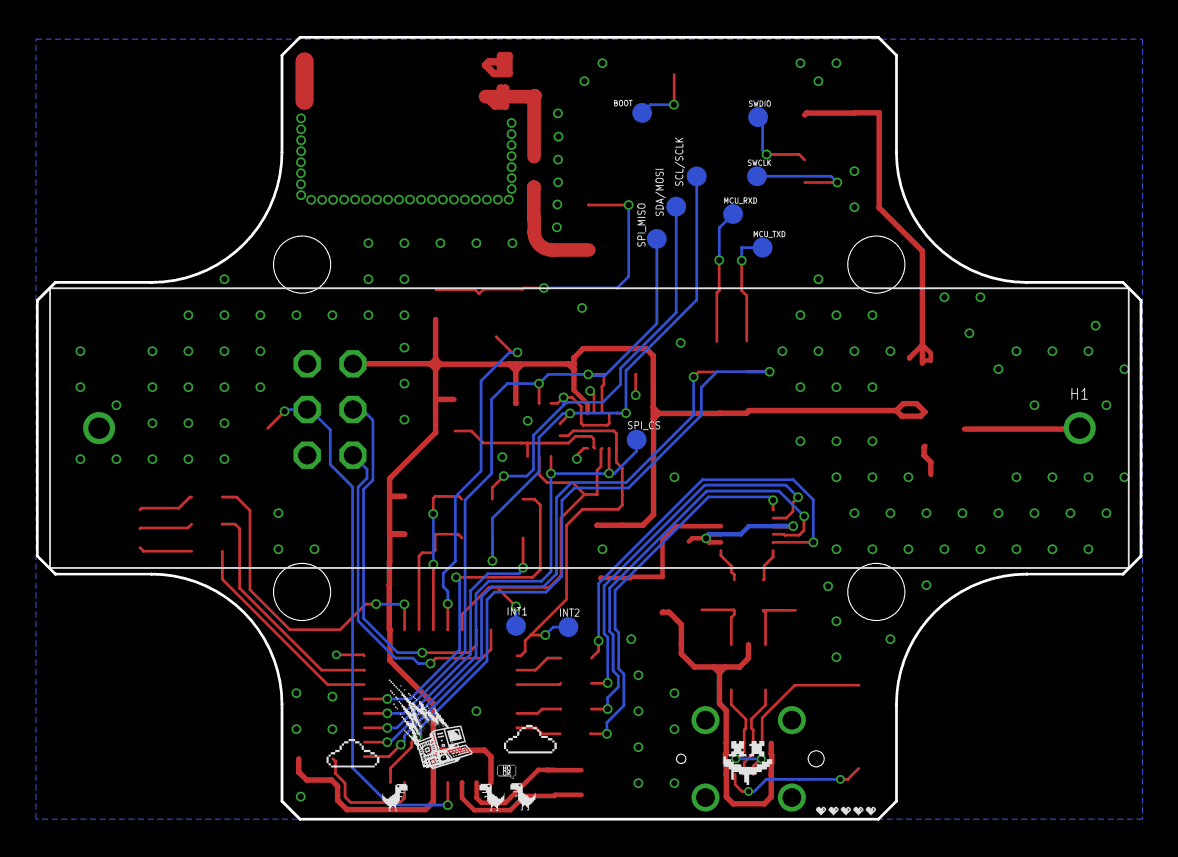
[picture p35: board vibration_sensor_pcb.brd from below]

Board: 2 copper layers, 61.3 x 43.4 mm, 75 parts (12 on the bottom side), 57 nets.

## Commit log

2025-02-06 Actualización README y aechivos de interes
2025-02-12 update readme with doing in last week
    [vibration_sensor_pcb.brd, vibration_sensor_pcb.sch]
2025-02-15 add and update pcb design with lora, stm, battery
    [vibration_sensor_pcb.brd, vibration_sensor_pcb.sch]
2025-02-16 add new design with other modules
    [vibration_sensor_pcb.brd, vibration_sensor_pcb.sch]
2025-02-18 UPDATE informacion ent1 y diseño pcb y materiales
2025-02-22 ADD documentacion de componentes
2025-03-06 UPLOADING todo el diseño nuevo de pcb con conexiones de spi e i2c
    [vibration_sensor_pcb.brd, vibration_sensor_pcb.sch]
2025-03-11 ADD crista sensor hall
    [vibration_sensor_pcb.brd, vibration_sensor_pcb.sch]
2025-03-19 UPDATE se agregan y conectan componentes de pcb, mosfet, jumpers...
    [vibration_sensor_pcb.brd, vibration_sensor_pcb.sch]
2025-03-19 UPDATE nueva hoja con usb y diversas conecciones antes de ruteo
    [vibration_sensor_pcb.brd, vibration_sensor_pcb.sch]
2025-03-19 UPDATE casi terminacion del diseño, cambiar efecto hall y conectar ruteo
    [vibration_sensor_pcb.brd, vibration_sensor_pcb.sch]
2025-03-27 UPDATE orden de pcb y reglas de diseño
    [vibration_sensor_pcb.brd, vibration_sensor_pcb.sch]
2025-03-28 UPDATE bloques y 3d
    [S3L-272013.stp]
2025-03-29 ADD & UPDATE documentacion, modelado 3d y poco ruteo
    [vibration_sensor_pcb.brd, vibration_sensor_pcb.sch]
2025-03-29 UPDATE schematic
    [vibration_sensor_pcb.brd, vibration_sensor_pcb.sch]
2025-03-30 UPDATE schematic and PCB route
    [vibration_sensor_pcb.brd, vibration_sensor_pcb.sch]
2025-04-07 UPDATE pcb schematic
    [copper_bottom.gbr, copper_top.gbr, drill_1_16.xln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]
2025-04-10 UPDATE file of the project
    [Caja_IDIE.step, S3L-272013.stp, caja_IDIE.stl]
2025-04-12 UPDATE pcb
2025-05-30 LAST UPDATE
    [BillOfMaterials.csv, Caja_IDIE.step, IDIE MOUSER.xlsx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]
